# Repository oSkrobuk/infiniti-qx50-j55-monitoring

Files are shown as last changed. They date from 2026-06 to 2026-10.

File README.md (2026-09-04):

# Infiniti QX50 J55 Monitoring

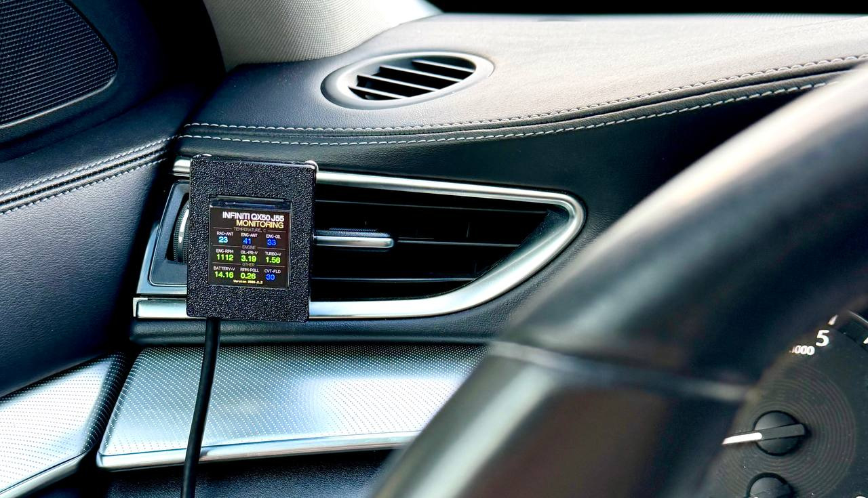
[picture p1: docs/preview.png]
Infiniti QX50 J55 Monitoring


Infiniti QX50 J55 Monitoring — компактный бортовой монитор для Infiniti QX50 J55. Он показывает
важные параметры двигателя, вариатора и бортовой сети на отдельном дисплее, а при опасных
значениях привлекает внимание цветом и звуковым сигналом.

## Что умеет устройство

- показывает температуры моторного масла, охлаждающей жидкости двигателя, радиатора и масла CVT
- отображает обороты двигателя, напряжение бортовой сети, давление масла и наддув
- выделяет нормальные, переходные и опасные значения разными цветами
- подаёт звуковой сигнал и показывает предупреждение при выходе параметров за заданные пределы
- сохраняет журнал предупреждений
- позволяет смотреть текущие показатели и менять настройки с телефона через веб-интерфейс
- поддерживает обновление прошивки по WiFi и возврат к предыдущей версии

## Что показывает дисплей

На дисплее показаны девять метрик в трёх группах. Обозначения одинаковы на дисплее и на странице
онлайн-мониторинга в веб-интерфейсе.

| Группа | Метка | Что означает | Единица |
|---|---|---|---|
| Температура | **RAD-ANT** | Температура охлаждающей жидкости в радиаторе | °C |
| Температура | **ENG-ANT** | Температура охлаждающей жидкости двигателя | °C |
| Температура | **ENG-OIL** | Температура моторного масла | °C |
| Двигатель | **ENG-RPM** | Обороты двигателя | об/мин |
| Двигатель | **OIL-PR-V** | Напряжение датчика давления масла | В |
| Двигатель | **TURBO-V** | Напряжение датчика давления наддува | В |
| Прочее | **BATTERY-V** | Напряжение бортовой сети | В |
| Прочее | **RPM-POLL** | Интервал между обновлениями оборотов | с |
| Прочее | **CVT-FLD** | Температура масла вариатора | °C |

`OIL-PR-V` и `TURBO-V` показывают напряжение, которое поступает от соответствующего датчика, а не
давление в физических единицах. `RPM-POLL` — не время ответа блока управления, а фактическая
частота обновления показаний оборотов: чем меньше значение, тем быстрее обновляются данные.

Цвет показания помогает оценить его состояние:

| Цвет | Значение |
|---|---|
| 🔵 Синий | Данных нет, агрегат не прогрет или ещё не готов к работе |
| 🟢 Зелёный | Нормальный рабочий диапазон |
| 🟡 Жёлтый | Переходная зона |
| 🔴 Красный | Значение вышло за пределы нормы |

Пороговые значения и цветовые зоны можно изменить через веб-интерфейс.

## Предупреждения и их значения

Если опасное значение сохраняется дольше настроенного времени подтверждения, устройство подаёт
звуковой сигнал, на пять секунд показывает код предупреждения поверх метрик и сохраняет событие
в журнале. Пороги в таблице указаны для заводской конфигурации и могут быть изменены
через настройки в браузере по адресу [http://192.168.4.1](http://192.168.4.1), подключившись
по WiFi (см. раздел [«WiFi и веб-интерфейс»](#wifi-и-веб-интерфейс)).

| Код | Что означает | Заводской порог |
|-----|---|---|
| **E01** | Температура моторного масла слишком высокая | Выше 98 °C |
| **E02** | Температура охлаждающей жидкости двигателя слишком высокая | Выше 96 °C |
| **E03** | Температура охлаждающей жидкости в радиаторе слишком высокая | Выше 90 °C |
| **E04** | Температура масла вариатора слишком высокая | Выше 100 °C |
| **E05** | Превышены допустимые обороты двигателя | Выше 6500 об/мин |
| **E06** | Напряжение бортовой сети слишком низкое | Ниже 11,5 В |
| **E07** | Напряжение бортовой сети слишком высокое | Выше 15,0 В |
| **E08** | Сигнал датчика давления масла ниже нормы для текущих оборотов | Ниже 1,4 В до 3000 об/мин или ниже 2,9 В от 3000 об/мин |
| **E09** | Разница температур масла и охлаждающей жидкости двигателя слишком высокая | Выше 14 °C |

Наличие кода в журнале означает, что такое состояние было зафиксировано ранее: оно не обязательно
сохраняется в текущий момент. Текущие значения следует проверить на дисплее или странице
онлайн-мониторинга. После очистки журнала предупреждение появится снова, если причина не устранена.

## Что требуется от пользователя

После установки и подключения — ничего. Не нужно запускать приложение, создавать учётную запись,
подключать устройство к интернету или выполнять какие-либо действия перед поездкой. Включите
зажигание — монитор включится вместе с автомобилем и начнёт работать автоматически.

Устройство получает данные через штатную автомобильную шину CAN. Она предназначена для обмена
данными между электронными блоками автомобиля и диагностическим оборудованием; монитор использует
стандартные диагностические запросы для чтения показателей.

## WiFi и веб-интерфейс

WiFi нужен только тогда, когда вы хотите открыть настройки или посмотреть показатели в браузере.
Интернет для соединения с устройством не требуется.

1. Подключитесь с телефона или ноутбука к сети `QX50Monitoring`
2. Введите пароль `infiniti`
3. Откройте в браузере [http://192.168.4.1](http://192.168.4.1)

В веб-интерфейсе доступны текущие показатели, отдельная страница работоспособности устройства,
журнал предупреждений, настройка порогов, режимов оповещения и яркости поддерживаемых дисплеев,
изменение имени и пароля WiFi, а также обновление прошивки. На Android при вопросе
о сети без доступа к интернету выберите «Остаться подключённым». Мобильный интернет отключать не
нужно.

Страница [http://192.168.4.1/obd](http://192.168.4.1/obd) показывает поддерживаемые
стандартные OBD-II Mode 01 PID и девять уже используемых Infiniti UDS DID. Все PID
по умолчанию выключены и выбираются галочками. Пока страница открыта, прошивка раз в секунду
запрашивает каждый выбранный PID с настраиваемой паузой между запросами (по умолчанию 5 мс);
после закрытия опрос автоматически прекращается.
Основной опрос Infiniti DID всегда имеет приоритет и продолжает работать независимо от
диагностической страницы.

## Обновления и оплата

Обновлять прошивку регулярно не обязательно. Если устройство работает так, как вам нужно, можно
вообще не устанавливать новые версии. Обновление имеет смысл только ради новых возможностей или
нужного вам исправления и выполняется через веб-интерфейс.

Использование устройства бесплатно: нет подписки, обязательных платежей, платной активации или
облачного сервиса. Устройство работает автономно и не зависит от внешнего сервера.

## Лицензия

Проект предоставлен на условиях PolyForm Noncommercial License 1.0.0. Разрешены
использование, копирование, изменение и распространение в некоммерческих целях
при соблюдении условий лицензии. Любое коммерческое использование запрещено.
Полные условия находятся в файле [LICENSE](LICENSE).

## Дополнительная документация

- [Технические нюансы и подробное описание](docs/technical-details.md)
- [Сборка, подключение и первоначальная настройка](docs/build-and-setup.md)

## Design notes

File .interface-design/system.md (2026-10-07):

# Kanvex Web Interface

## Direction

- Feel: compact automotive diagnostic console with calm, technical hierarchy
- Domain cues: CAN bus, live telemetry, ECU diagnostics, warning states, workshop instruments
- Color world: graphite dashboard, black trim, muted steel, Infiniti gold, semantic green/red/blue
- Signature: gold diagnostic labels and large monospaced live values on dark instrument-like surfaces

## Depth and spacing

- Use borders-only depth with quiet dark surface shifts; avoid decorative shadows and gradients
- Base spacing unit: 4 px
- Control gaps: 8–12 px; card padding: 14–16 px; section gaps: 24–28 px
- Buttons use an 8 px radius; cards use 10 px; dialogs use 12 px

## Hierarchy

- Live numeric values are the focal elements: 25 px, semibold, monospaced
- Metric names are secondary and muted; PID/DID identifiers use the gold accent
- Supporting notes use muted text with approximately 1.45 line height
- Preserve the established graphite-and-gold palette and existing system font stack

## Navigation pattern

- Main navigation uses equal-width grid buttons with centered labels and visible icons
- Desktop: three equal columns, centered, with a maximum total width of 700 px
- Up to 640 px: two equal columns; an unpaired final button keeps one-column width and never stretches across the row
- Mobile navigation buttons have a minimum height of 54 px and may wrap labels without horizontal scrolling
- Keep every primary destination visible without a menu or disclosure control

## Diagnostic cards

- Use the existing bordered dark card with gold PID/DID identifier, muted name, and monospaced value
- Put contextual help in a native button and native dialog
- Dim stale values without hiding enabled controls
- Convert raw OBD values only when the PID formula is verified; explain bit fields or discarded status flags in help text

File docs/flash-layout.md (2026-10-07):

# Разделы флеш-памяти

Расчет обновлен 7 октября 2026 года по бинарникам четырех окружений после полной сборки
`platformio run`.

## Размеры прошивки

| Окружение | Размер `firmware.bin` | Размер OTA-слота | Свободно | Заполнение |
|---|---:|---:|---:|---:|
| `esp32` | 1 191 920 байт | 1 835 008 байт | 643 088 байт | 64,9% |
| `esp32-mock` | 1 186 464 байта | 1 835 008 байт | 648 544 байта | 64,7% |
| `esp32s3-wt32` | 1 227 872 байта | 6 553 600 байт | 5 325 728 байт | 18,7% |
| `esp32s3-wt32-mock` | 1 219 664 байта | 6 553 600 байт | 5 333 936 байт | 18,6% |

После интеграции BLE фактический размер нужно проверить повторно. CI ограничивает DEVKIT1 размером
старого OTA-слота `0x1C0000` (1 835 008 байт), независимо от дальнейших изменений CSV.

## ESP32 DEVKIT1, 4 МБ

Используется [`partitions_4mb.csv`](../partitions_4mb.csv):

| Раздел | Смещение | Размер |
|---|---:|---:|
| `nvs` | `0x9000` | 20 КБ |
| `otadata` | `0xE000` | 8 КБ |
| `ota_0` | `0x10000` | 1,75 МБ |
| `ota_1` | `0x1D0000` | 1,75 МБ |
| `spiffs` | `0x390000` | 448 КБ |

Два одинаковых OTA-слота сохраняют обновление с откатом. NVS в 20 КБ остается на прежнем
месте, а LittleFS на 448 КБ хранит JSON-файлы конфигурации и журналов. Веб-интерфейс
скомпилирован в прошивку.

## WT32-SC01 Plus, 16 МБ

Используется [`partitions_16mb.csv`](../partitions_16mb.csv). Раскладка совпадает с базовой
`default_16MB.csv` Arduino ESP32, но закреплена в репозитории явно:

| Раздел | Смещение | Размер |
|---|---:|---:|
| `nvs` | `0x9000` | 20 КБ |
| `otadata` | `0xE000` | 8 КБ |
| `ota_0` | `0x10000` | 6,25 МБ |
| `ota_1` | `0x650000` | 6,25 МБ |
| `spiffs` | `0xC90000` | 3,375 МБ |
| `coredump` | `0xFF0000` | 64 КБ |

Старая общая 4-мегабайтная таблица оставляла на WT32 неразмеченными 12 582 912 байт, то есть
ровно 12 МБ. Новая таблица использует все 16 МБ и оставляет большой запас для BLE и дальнейшего
роста прошивки.

## Переход существующих устройств

OTA обновляет только неактивный раздел приложения и не записывает таблицу разделов. Один и тот же
`firmware.bin` использует таблицу разделов, уже установленную на устройстве, поэтому обычное
Wi-Fi-обновление не требует миграции разметки. Устройства с временно выпускавшейся увеличенной
разметкой (слоты по 1,875 МБ и LittleFS 192 КБ) продолжают работать с ней после OTA.

USB-комплект содержит текущую классическую таблицу. Запись `partitions.bin` на устройство с
увеличенной разметкой меняет адрес и размер LittleFS и может сделать настройки и журналы
недоступными. Обычное обновление выполняйте по Wi-Fi только файлом `firmware.bin`. Менять таблицу
через USB можно лишь отдельной процедурой после резервного копирования данных и проверки текущей
разметки; Kanvex Service Tool пока не автоматизирует безопасную миграцию.

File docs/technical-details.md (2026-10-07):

# Технические нюансы Infiniti QX50 J55 Monitoring

Infiniti QX50 J55 Monitoring

Бортовой монитор на ESP32 с TFT-дисплеем и веб-интерфейсом настройки.
Считывает параметры автомобиля через диагностический протокол UDS (ISO 14229) по шине CAN (OBD-II).
При выходе параметров за пределы нормы — воспроизводит звуковой сигнал через бузер и показывает оверлей на дисплее.

В версии прошивки XXXX.Y.Z каждое число означает следующее:
1. XXXX — год выпуска релиза прошивки.
2. Y — мажорная версия (Major). Указывает на крупные изменения, новые функции или глобальное обновление архитектуры.
3. Z — минорная версия (Minor). Указывает на мелкие доработки, исправления ошибок или добавление небольших возможностей в рамках текущего мажора.

Версия задается в одном месте — `FW_VERSION` в [include/Version.h](../include/Version.h). Оттуда она
попадает на дисплей, в `GET /version` и `GET /metrics`, и с ней же CI сверяет имя тега при релизе.

---

## Поддерживаемые платформы

| Платформа | Дисплей | Окружение сборки |
|---|---|---|
| **ESP32 DEVKIT1** | ST7789 240×240 SPI | `esp32`, `esp32-mock` |
| **WT32-SC01 Plus ESP32-S3** | ST7796 320×480 8-бит параллельный | `esp32s3-wt32`, `esp32s3-wt32-mock` |

---

## Необходимое оборудование

### Вариант A: ESP32 DEVKIT1

| Компонент | Описание |
|---|---|
| **ESP32 DEVKIT1** | Основной микроконтроллер. Любая плата на базе ESP32 с 30 или 38 пинами (DEVKIT V1 / DOIT). |
| **IPS TFT ST7789** | Дисплей 240×240 пикселей, интерфейс SPI, питание 3.3 В. |
| **WVCMCU-230** | CAN-трансивер на базе SN65HVD230, питание 3.3 В, подключается к OBD-II разъёму автомобиля. |
| **Пассивный бузер** | Пьезоизлучатель для звукового оповещения об алертах. Подключается к GPIO 26 через резистор 1кОм и 2N5551. |
| **DC-DC** | Преобразователь напряжения 12–24 В в 5 В. |
| **Провода** | Соединительные провода (желательно разных цветов для удобства монтажа). |
| **Паяльник + припой** | Для надёжного соединения проводов с платами. |

### Вариант B: WT32-SC01 Plus ESP32-S3

| Компонент | Описание |
|---|---|
| **WT32-SC01 Plus** | Плата с встроенным дисплеем ST7796 320×480 и ESP32-S3-WROVER-N16R2 (16 МБ Flash, 2 МБ PSRAM). |
| **WVCMCU-230** | CAN-трансивер на базе SN65HVD230, питание 3.3 В, подключается к OBD-II разъёму автомобиля. |
| **Пассивный бузер** | Пьезоизлучатель для звукового оповещения об алертах. Подключается к GPIO 12 через резистор 1кОм и 2N5551. |
| **DC-DC** | Преобразователь напряжения 12–24 В в 5 В. |
| **Провода** | Соединительные провода (желательно разных цветов для удобства монтажа). |
| **Паяльник + припой** | Для надёжного соединения проводов с платами. |

> Дисплей встроен в плату WT32-SC01 Plus и не требует отдельного подключения.
> Яркость встроенной подсветки регулируется через аппаратный BL_PWM на GPIO 45.

---

## 1. Подключение оборудования

### TFT-дисплей (ST7789, 240×240) — только для ESP32 DEVKIT1

| Дисплей | ESP32 GPIO | Описание |
|---|---|---|
| SDA / MOSI | GPIO **23** | Данные SPI |
| SCL / SCLK | GPIO **18** | Тактирование SPI |
| RES / RST  | GPIO **4**  | Сброс дисплея |
| DC / RS | GPIO **15** | Данные / команда |
| BLK | GPIO **27** через 500 Ом | Управление яркостью, если вывод есть |
| CS | — | Не подключать (CS=-1, дисплей всегда выбран) |
| VCC | **3.3 В** | Питание |
| GND | **GND** | Земля |

> Дисплей работает на 3.3 В. Не подключайте к 5 В — это выведет его из строя.
>
> Вывод BLK необязателен. Одна и та же прошивка работает с дисплеями без BLK и с дисплеями, у которых
> BLK подключен к GPIO 27. Во втором случае яркость регулируется через веб-интерфейс от 10 до 100%.
> Если BLK конкретного модуля напрямую питает светодиоды, а не является управляющим входом,
> используйте транзистор или MOSFET согласно документации модуля.

---

### Питание WT32-SC01 Plus

Преобразователь DC-DC понижает бортовое напряжение 12–14 В до 5 В. Выход `+5 В` подключается к
контакту 1 разъема `EXT_IO_1`, а выход `GND` — к контакту 2. Контакты считаются слева направо,
если смотреть на плату так же, как на схеме подключения.

Питание 3,3 В для WVCMCU-230 и цепи пассивного бузера берется с контакта 2 разъема `EXT_IO_2`,
второго слева. Земля CAN-трансивера и бузера подключается непосредственно к `GND` выхода DC-DC;
таким образом, все компоненты имеют общую землю.

---

### CAN-модуль WVCMCU-230 (SN65HVD230) — для обеих платформ

| Модуль | ESP32 DEVKIT1 | WT32-SC01 Plus | Описание |
|---|---|---|---|
| CTX | GPIO **32** | GPIO **10**, `EXT_IO_1` контакт 3 слева | CAN TX (МК → трансивер) |
| CRX | GPIO **34** | GPIO **11**, `EXT_IO_1` контакт 4 слева | CAN RX (трансивер → МК) |
| VCC | **3,3 В** | **3,3 В**, `EXT_IO_2` контакт 2 слева | Питание |
| GND | **GND** | `GND` выхода DC-DC | Общая земля |
| CANH | OBD-II пин **6** | OBD-II пин **6** | Шина CAN High |
| CANL | OBD-II пин **14** | OBD-II пин **14** | Шина CAN Low |

> На WT32-SC01 Plus GPIO 10 и GPIO 11 выведены на разъем `EXT_IO_1` и не конфликтуют со встроенными
> дисплеем и сенсорной панелью.

> ESP32 активно опрашивает блоки управления двигателем (ECM) и трансмиссией (TCM) по протоколу UDS, отправляя запросы `ReadDataByIdentifier` (сервис 0x22). Это безопасно: запросы стандартны, используются штатным дилерским оборудованием.

> Скорость шины: **500 кбит/с** (стандарт для большинства автомобилей, в т.ч. Infiniti QX50 J55).

---

### Пассивный бузер — для обеих платформ

| Бузер | ESP32 DEVKIT1 | WT32-SC01 Plus | Описание |
|---|---|---|---|
| Питание | **3,3 В** | **3,3 В**, `EXT_IO_2` контакт 2 слева | Питание бузера |
| Управление | GPIO **26** | GPIO **12**, `EXT_IO_1` контакт 5 слева | Через резистор 1 кОм и 2N5551 |
| GND | **GND** | `GND` выхода DC-DC | Общая земля |

При включении устройства бузер воспроизводит короткую мелодию приветствия (в стиле BIOS POST). При срабатывании алерта — сигнал оповещения.

> На WT32-SC01 Plus есть встроенный I2S-усилитель 2,5 Вт и выход `SPK+/SPK-`, но самого динамика
> на плате нет. Текущая прошивка этот выход не использует и воспроизводит сигналы внешним пассивным
> бузером на GPIO 12.

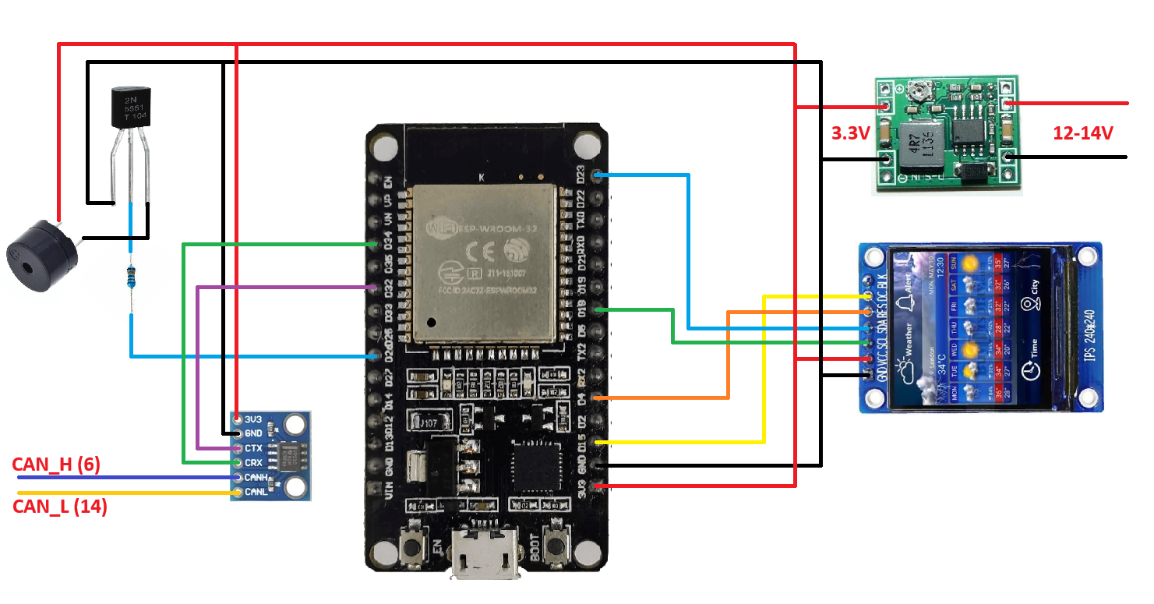
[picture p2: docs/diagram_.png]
Схема подключения ESP32 DEVKIT1


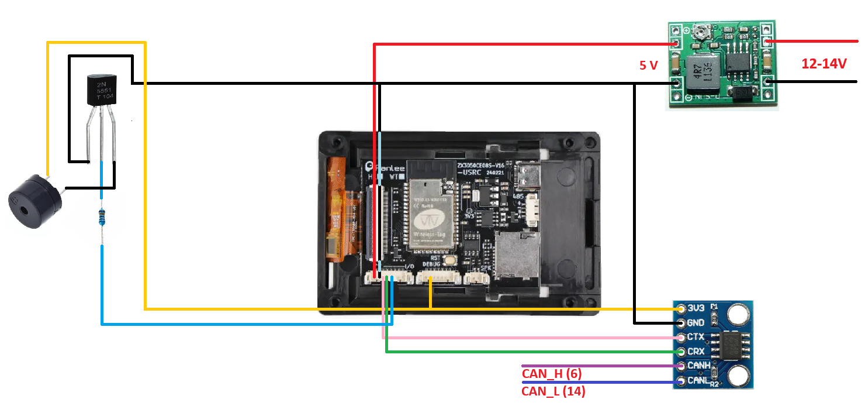
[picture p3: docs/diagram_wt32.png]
Схема подключения WT32-SC01 Plus


---

### Корпус

Корпус для дисплея 1,3″ печатаем на 3D-принтере пластиком PETG или ABS. Есть два варианта корпуса:

1. [Первая версия](../stl/full_v1_1.3in_display.stl)
2. Измененная Александром: [корпус МК](../stl/mc_housing_v2),
   [корпус дисплея](../stl/display_housing_v2_1.3in). Отличается переносом и
   углублением отверстий под провода, дополнительным зажимом на крышке МК и простым
   креплением дисплея в дефлектор

---

## 2. USB-устройство в WSL

ESP32 DEVKIT1 подключается через мост CP2102, CH340 или CH9102. WT32-SC01 Plus
использует встроенный USB Serial/JTAG. Передайте USB-устройство в WSL и проверьте
доступный Linux-порт:

```bash
ls -l /dev/ttyUSB* /dev/ttyACM* 2>/dev/null
```

Обычно DEVKIT1 появляется как `/dev/ttyUSB0`, а WT32 — как `/dev/ttyACM0`. Если
у текущего пользователя нет доступа к порту, добавьте его в группу `dialout`, затем
перезапустите сеанс WSL:

```bash
sudo usermod -aG dialout "$USER"
```

---

## 3. Первичная прошивка из WSL через esptool

Команды этого раздела выполняет только владелец устройства. Для ESP32 DEVKIT1 нужны
`bootloader.bin`, `partitions.bin` и `firmware.bin`:

```bash
python3 -m esptool --chip esp32 --port /dev/ttyUSB0 --baud 921600 erase_flash
python3 -m esptool --chip esp32 --port /dev/ttyUSB0 --baud 921600 \
  write_flash --flash_mode dio --flash_freq 40m \
  0x1000 bootloader.bin 0x8000 partitions.bin 0x10000 firmware.bin
```

Для WT32-SC01 Plus нужны `bootloader_s3.bin`, `partitions_s3.bin` и
`firmware_s3.bin`. Загрузчик от ESP32 DEVKIT1 использовать нельзя:

```bash
python3 -m esptool --chip esp32s3 --port /dev/ttyACM0 --baud 460800 erase_flash
python3 -m esptool --chip esp32s3 --port /dev/ttyACM0 --baud 460800 \
  write_flash --flash_mode qio --flash_freq 80m --flash_size 16MB \
  0x0000 bootloader_s3.bin 0x8000 partitions_s3.bin 0x10000 firmware_s3.bin
```

Для входа WT32 в загрузчик подключите плату по USB-C, зажмите `BOOT`, нажмите и
отпустите `RESET`, затем отпустите `BOOT`. После прошивки нажмите `RESET`.

---

## 4. Мониторинг UART из WSL

Подключите терминал PlatformIO к тому же Linux-порту со скоростью 115200 бод:

```bash
platformio device monitor --port /dev/ttyUSB0 --baud 115200
```

Для WT32 обычно нужно заменить порт на `/dev/ttyACM0`. После нажатия `EN` или
`RESET` в терминале появится журнал загрузки, состояние CAN-шины, ответы UDS,
значения датчиков и срабатывания алертов.

> Если в окне нет вывода — проверьте правильность порта COM и скорость 115200. Порт должен совпадать с тем, что отображается в Диспетчере устройств (**Silicon Labs CP210x**).

> **Предупреждения при старте — это нормально.** При каждом включении ESP32 ROM-загрузчик выводит несколько служебных строк на скорости 74880 бод (не 115200), поэтому терминал может показать их как мусор: `RX FRAMING ERROR`, `invalid UTF-8 byte sequence`, `No core dump partition found`. Эти сообщения не относятся к нашему коду и не влияют на работу устройства — просто игнорируйте их.

---

## 5. Подключение к WiFi и веб-интерфейс

ESP32 создаёт собственную точку доступа (Access Point) — интернет не нужен.

| Параметр | Значение по умолчанию |
|---|---|
| Сеть | `QX50Monitoring` |
| Пароль | `infiniti` |
| Адрес | http://192.168.4.1 |

> Имя сети и пароль можно изменить через веб-интерфейс (раздел **«1. Настройка WiFi»**).
> После сохранения устройство перезагрузится с новыми настройками.

**Шаги:**

1. На телефоне или ноутбуке откройте список WiFi-сетей.
2. Подключитесь к сети **QX50Monitoring**, пароль `infiniti`.
3. Откройте браузер и перейдите по адресу **http://192.168.4.1**.
4. Откроется страница редактора конфигурации.
5. Можно забыть WiFi-сеть, чтобы телефон не подключался автоматически.

> **Мобильный интернет на телефоне продолжает работать.** Устройство намеренно не отдает
> по DHCP адрес шлюза, поэтому телефон не делает нашу сеть основной: запросы на `192.168.4.1`
> идут по WiFi, все остальные — по мобильной сети. Android при подключении спросит «Сеть не имеет
> доступа к интернету. Остаться подключенным?» — ответьте **«Да»**.
>
> Передачу данных **отключать не нужно** — без нее не работает проверка обновлений (глава 6).
> Отключить ее имеет смысл только если конкретный телефон все равно упорно теряет интернет:
> веб-интерфейс и OTA от этого работать не перестанут.

### HTTP API

| Метод | Путь | Описание |
|---|---|---|
| `GET`  | `/` | Главная страница (HTML) — редактор конфигурации |
| `GET`  | `/live` | Страница онлайн мониторинга (HTML) — метрики в реальном времени |
| `GET`  | `/health` | Страница работоспособности устройства (HTML) |
| `GET`  | `/metrics` | Текущие значения метрик и их состояния (JSON, включая `version`) |
| `GET`  | `/reset-history`  | История причин последних загрузок устройства (JSON) |
| `GET`  | `/version` | Версия прошивки, метка сборки, слот OTA, окружение, аптайм (JSON) |
| `GET`  | `/config` | Текущий конфиг порогов (JSON) |
| `POST` | `/config` | Сохранить конфиг порогов (JSON body) |
| `POST` | `/reset` | Сбросить конфиг порогов к заводским значениям |
| `GET`  | `/wifi` | Текущие WiFi-настройки (JSON: ssid, password) |
| `POST` | `/wifi` | Сохранить WiFi-настройки (JSON body) |
| `POST` | `/restart` | Перезагрузить устройство |
| `GET`  | `/alerts` | Журнал сработавших алертов (JSON) |
| `POST` | `/alerts-clear` | Очистить журнал алертов |
| `GET`  | `/checks` | Конфиг проверок алертов (JSON) |
| `POST` | `/checks` | Сохранить конфиг проверок (JSON body) |
| `GET`  | `/update` | Страница OTA-обновления прошивки (редирект на `/`) |
| `POST` | `/update` | Загрузить `.bin` файл прошивки (multipart) |
| `GET`  | `/slots` | Что записано в обоих слотах OTA (JSON) |
| `POST` | `/boot-slot` | Сделать слот загрузочным (`?slot=ota_0` или `?slot=ota_1`) |

Ответ `GET /version`:

```json
{
  "version": "2026.3.1",
  "build": "Jul 27 2026 14:02:11",
  "slot": "ota_0",
  "env": "esp32",
  "uptime_s": 12345
}
```

`slot` — раздел, из которого загрузилась работающая прошивка (`ota_0` или `ota_1`),
`env` — окружение сборки (`esp32`, `esp32-mock`, `esp32s3-wt32`, `esp32s3-wt32-mock`).

Ответ `GET /slots`:

```json
{
  "slots": [
    {
      "label": "ota_0", "valid": true, "running": true, "boot": true, "compatible": true,
      "version": "2026.3.3", "env": "esp32", "build": "Aug  6 2026 01:15:19",
      "size": 1835008, "used": 1080325, "address": 65536
    },
    {
      "label": "ota_1", "valid": true, "running": false, "boot": false, "compatible": true,
      "version": "2026.3.2", "env": "esp32", "build": "Aug  3 2026 04:49:07",
      "size": 1835008, "used": 1076032, "address": 1900544
    }
  ]
}
```

`valid` — в слоте лежит образ приложения, `running` — из него работает прошивка сейчас,
`boot` — с него устройство загрузится после перезагрузки, `compatible` — разрешено ли ручное
переключение, `used` — длина образа в байтах, `address` — адрес раздела во flash.
Пустые `version`, `env` и `build` означают, что в образе нет маркера версии (прошивка старее
этой возможности) — см. главу 6.

### Онлайн мониторинг (веб)

Страница **http://192.168.4.1/live** (ссылка **«📊 Онлайн мониторинг →»** на главной)
показывает все метрики в реальном времени прямо в браузере — удобно, когда дисплей не виден.

- **Сетка метрик** — 9 карточек по 3 в ряд, в том же порядке, что и на дисплее:
  RAD-ANT · ENG-ANT · ENG-OIL / ENG-RPM · OIL-PR-V · TURBO-V / BATTERY-V · RPM-POLL · CVT-FLD.
  Значения обновляются каждые **0.5 сек** (опрос `/metrics`), цвет левой полосы и числа
  отражает состояние (синий / зелёный / жёлтый / красный / серый «нет данных»).
- **Индикатор связи** — строка «В сети · v2026.3.1 · обновлено ЧЧ:ММ:СС · аптайм …» либо
  «Нет связи с устройством». Версия прошивки приходит в том же ответе `/metrics`.
- **Баннер ошибок** — красная плашка «⚠ Зафиксированы ошибки…» появляется, если в журнале
  есть срабатывания, и исчезает после его очистки.
- **История срабатываний** — та же таблица журнала алертов, что и на главной, с кнопкой
  **«🗑 Очистить историю»**. Обновляется каждые **5 сек** и сразу после очистки.

---

## 6. OTA — обновление прошивки по воздуху

После первой прошивки через USB все последующие обновления можно загружать **без кабеля** прямо через браузер.

### Что нужно

- Файл `firmware.bin` новой версии (из релиза или собранный PlatformIO: `.pio/build/esp32/firmware.bin`).
- Подключение к точке доступа **QX50Monitoring**.

### Порядок обновления

1. Подключитесь к WiFi-сети **QX50Monitoring** (пароль `infiniti`).
2. Откройте **http://192.168.4.1** в браузере.
3. Прокрутите страницу вниз до раздела **«↑ OTA — Обновление прошивки»**.
4. Нажмите **«Выбрать .bin»** и укажите файл `firmware.bin`.
5. Нажмите **«↑ Загрузить»** и подтвердите в диалоге.
6. Дождитесь заполнения прогресс-бара и сообщения **«✓ Прошивка записана. Перезагрузка...»**.
7. ESP32 автоматически перезагрузится с новой прошивкой (~2–3 секунды).

> **Страница перестанет отвечать** на время перезагрузки — это нормально. Через 5–10 секунд обновите страницу браузера.

> **Первичная прошивка через USB обязательна.** OTA-обновления возможны только после того, как устройство хотя бы один раз прошито через USB с помощью `esptool` или PlatformIO.

### Проверка обновлений

В том же разделе **«↑ 6. Обновление прошивки»**, над формой загрузки `.bin`, лежит карточка
**«↻ Проверка обновлений»**: текущая версия прошивки, метка сборки со слотом OTA и кнопка
**«↻ Проверить обновления»**.

Устройство в интернет не выходит, поэтому релизы спрашивает **браузер телефона**: запрос
на `192.168.4.1` идет по WiFi, запрос к `api.github.com` — по мобильной сети.

**Автопроверка при открытии страницы.** Главная страница проверяет релизы сама, в фоне —
загрузку и работу интерфейса это не задерживает, а при отсутствии интернета просто ничего
не происходит. Если на GitHub версия новее, поверх страницы появляется окно **«↑ Доступна
новая прошивка»** с кнопками **«Перейти к обновлению»** (открывает и прокручивает к разделу 5)
и **«Позже»**; окно закрывается также кликом по затемнению или клавишей Esc.

Проверка идет не чаще **одного раза в 5 минут**: время последней попытки лежит
в `localStorage` браузера, поэтому перезагрузка страницы, закрытие вкладки и перезапуск
браузера отсчет не сбрасывают — иначе несколько открытий страницы подряд быстро упирались бы
в лимит GitHub. Кнопка **«↻ Проверить обновления»** этот интервал игнорирует и работает всегда.

**Что нужно от телефона:**

- включенная передача данных (мобильный интернет);
- разрешение остаться в сети без интернета — на вопрос Android «Сеть не имеет доступа
  к интернету. Остаться подключенным?» ответьте **«Да»**.

**Что показывает кнопка:**

| Ситуация | Сообщение |
|---|---|
| Есть версия новее | «Доступна версия X (у вас Y)» + описание релиза и ссылки на релиз и `firmware.bin` |
| Установлена актуальная | «✓ Установлена последняя версия X» |
| Релизов нет | «Релизы еще не опубликованы» |
| Слишком частые проверки | «Превышен лимит запросов к GitHub, попробуйте позже» — без авторизации GitHub отдает 60 запросов в час на один адрес |
| Нет интернета у телефона | «Нет доступа к интернету» + напоминание включить мобильные данные |

Запрос обрывается через **5 секунд**: в сети без интернета DNS не отвечает, и ждать дольше
нечего. Ссылка **«Все релизы»** под карточкой ведет на страницу релизов напрямую и работает,
даже если проверка не прошла.

Если релиз новее, в карточке появляется кнопка **«↓ Скачать и установить»**: браузер сам скачивает
OTA-образ для подключенной платы и сразу отдает его в прошивку, прогресс идет в полосе формы ниже.

Файл берется не из ассетов релиза, а из служебной ветки `firmware`. WEB UI выбирает его
по окружению сборки устройства:

```
https://raw.githubusercontent.com/oSkrobuk/infiniti-qx50-j55-monitoring/firmware/<версия>/firmware.bin
https://raw.githubusercontent.com/oSkrobuk/infiniti-qx50-j55-monitoring/firmware/<версия>/firmware_s3.bin
```

Ассеты релизов GitHub отдает с хоста `release-assets.githubusercontent.com` **без заголовка
`Access-Control-Allow-Origin`**, и браузер не пускает такой ответ в скрипт — запрос падает
еще до чтения файла (Safari сообщает об этом первым, но так ведут себя все браузеры).
У `raw.githubusercontent.com` заголовок есть, поэтому CI на каждом теге кладет прошивку
еще и в ветку `firmware`, в папку с номером версии. Версия в пути означает, что на
устройство не может приехать `.bin` от другого релиза.

Если скачать не удалось (сборки этой версии в ветке еще нет, оборвалась сеть), в карточке
появляется подсказка с причиной — скачайте `.bin` вручную по ссылке и залейте формой
**«↑ OTA — Загрузка .bin»**. Ручной способ работает всегда: обычное скачивание по ссылке
идет средствами браузера, и CORS ему не нужен.

Для ESP32 DEVKIT1 скачивается `firmware.bin`, для WT32-SC01 Plus — `firmware_s3.bin`.

### Проверка совместимости OTA-образа

Автоматическая и ручная OTA-загрузка проходят одинаковую проверку на самом устройстве. Во время
приема файла прошивка ищет встроенный маркер `QX50-FW-TAG`, читает из него окружение сборки и до
активации нового слота сравнивает его с работающей платой.

Совместимыми считаются real- и mock-сборки одной аппаратной платформы:

- `esp32` и `esp32-mock` — ESP32 DEVKIT1
- `esp32s3-wt32` и `esp32s3-wt32-mock` — WT32-SC01 Plus

Автоматическое обновление mock-сборки загружает опубликованный real-образ той же платы. После
обновления устройство продолжит работу уже без симуляции данных.

Образ WT32 нельзя установить на ESP32 DEVKIT1 и наоборот. Файл без маркера, в том числе старая
или сторонняя прошивка, также отклоняется. Проверка выполняется до `Update.end(true)`, поэтому
отклоненный образ не становится загрузочным, а устройство продолжает работать с текущего слота.

Ограничение относится только к OTA через веб-интерфейс. При необходимости старый образ без маркера
по-прежнему можно записать вручную через USB-инструменты.

### Слоты прошивки и откат

Под карточкой проверки обновлений лежит карточка **«⇆ Слоты прошивки»**: для каждого из двух
слотов (`ota_0` и `ota_1`) видно, что в нем записано — версия, окружение сборки, дата сборки
и размер образа, — а также метки **«работает сейчас»** и **«загрузится после перезагрузки»**.

Кнопка **«⇆ Загрузиться отсюда»** у совместимого неактивного слота переключает загрузку на лежащую там
прошивку: устройство меняет запись в `otadata` и перезагружается. Так возвращаются к предыдущей
версии, если новая чем-то не устроила — заново качать `.bin` не нужно, старый образ никуда
не делся. Настройки, журнал алертов и файловая система лежат в отдельном разделе `spiffs`,
поэтому переключение слота их не меняет. Однако старая прошивка получает текущую конфигурацию,
которая может оказаться для нее несовместимой; автоматического отката после неудачной загрузки нет.

> Версию соседнего слота устройство читает прямо из его образа: при сборке в прошивку
> вшивается маркер `QX50-FW-TAG:версия|окружение|дата сборки|`, и он ищется линейным чтением
> раздела (результат кешируется по хешу образа, так что повторные открытия карточки бесплатны).
> У прошивок, собранных до появления этой карточки, маркера нет — для них показывается
> «Версия неизвестна», а ручное переключение запрещено. Сервер повторяет проверку образа,
> поэтому обойти ограничение прямым запросом к HTTP API нельзя.

### Как устроено OTA (техническая справка)

Для плат используются разные таблицы разделов. ESP32 DEVKIT1 с 4 МБ флеша получает два
OTA-слота по 1,75 МБ и LittleFS на 448 КБ. WT32-SC01 Plus с 16 МБ получает два слота по
6,25 МБ, LittleFS на 3,375 МБ и раздел coredump на 64 КБ. Полный расчет, размеры текущих
бинарников и порядок перехода приведены в [описании разделов флеша](flash-layout.md).

При OTA-обновлении:
1. Новая прошивка записывается в **неактивный** слот.
2. `otadata` обновляется, указывая на новый слот.
3. ESP32 перезагружается и загружается из нового слота.

Старая прошивка остаётся в предыдущем слоте до следующего OTA-обновления, и на нее можно
вернуться карточкой **«⇆ Слоты прошивки»**.

### Файлы LittleFS

В разделе `spiffs` (LittleFS, 448 КБ на ESP32 и 3,375 МБ на WT32) хранятся четыре файла:

| Файл | Описание |
|---|---|
| `/config.json` | Пороги метрик, параметры системы, яркость и настройки WiFi |
| `/checks.json` | Конфиг проверок алертов (тайминги + режим повтора + пороги) |
| `/alerts.json` | Журнал сработавших алертов (сохраняется между перезагрузками) |
| `/resets.json` | Причины последних десяти загрузок устройства |

---

## 7. Метрики на дисплее

Дисплей 240×240 разделён на три секции. Цвет каждого значения меняется плавно согласно настроенным порогам.

При срабатывании алерта дисплей переходит в **режим оверлея** — метрики скрываются и на весь экран отображается код и описание алерта (например, `E01 — Engine oil temperature exceeded maximum threshold`). Оверлей исчезает автоматически через **5 секунд**.

### TEMPERATURE — температурные датчики

| Метка | Описание | Единица |
|---|---|---|
| **RAD-ANT** | Температура антифриза в радиаторе | °C |
| **ENG-ANT** | Температура антифриза ДВС | °C |
| **ENG-OIL** | Температура моторного масла ДВС | °C |

Цвет меняется по схеме **синий → зелёный → красный** (холодно → норма → перегрев).

### ENGINE — параметры двигателя

| Метка | Описание | Единица |
|---|---|---|
| **ENG-RPM** | Обороты двигателя | об/мин |
| **OIL-PR-V** | Напряжение датчика давления масла ДВС | В |
| **TURBO-V** | Напряжение датчика давления наддува (турбина) | В |

### OTHER — прочие параметры

| Метка | Описание | Единица |
|---|---|---|
| **BATTERY-V** | Напряжение бортовой сети | В |
| **RPM-POLL** | Период обновления оборотов — интервал между двумя UDS-запросами RPM | с |
| **CVT-FLD** | Температура масла вариатора (CVT) | °C |

> **RPM-POLL — это не время ответа ECU.** Значение показывает, как часто устройство успевает
> обновлять обороты: отдельная задача по кругу опрашивает 8 параметров с паузой `poll_interval_ms`,
> поэтому RPM-POLL ≈ `poll_interval_ms × 8` (при 30 мс — около 0.24 с).

### Цветовая индикация

| Цвет | Значение |
|---|---|
| 🔵 Синий | Нет данных или агрегат не прогрет или не готов к работе |
| 🟢 Зелёный | Рабочий / нормальный диапазон |
| 🟡 Жёлтый | Переходная зона (плавный градиент) |
| 🔴 Красный | Выход за пределы нормы / перегрев |

---

## 8. Настройка порогов

Все пороги хранятся в файловой системе LittleFS (`/config.json`) и доступны для редактирования через веб-интерфейс.
`POST /config` принимает только известные секции и поля, проверяет типы, безопасные диапазоны и порядок порогов.
Некорректный запрос отклоняется целиком и не изменяет сохраненную конфигурацию.

Каждая карточка содержит кнопку **«↺ Сброс»** — сбрасывает поля только этой карточки к заводским значениям без сохранения. Кнопка **«↺ По умолчанию»** в разделе «Конфигурация метрик» сбрасывает весь конфиг и немедленно сохраняет его.

> При обновлении прошивки конфиг мигрирует по отдельным полям: известные пользовательские значения
> сохраняются, новые параметры получают актуальные значения по умолчанию, удаленные параметры
> отбрасываются. CRC32 блока defaults используется только для обнаружения необходимости миграции.

### 🌡️ Температурные датчики

Три порога: минимум (не прогрет), цель (рабочая температура), максимум (перегрев).

| Секция | Датчик | Мин, °C | Цель, °C | Макс, °C |
|---|---|---|---|---|
| `oil` | ENG-OIL — моторное масло ДВС | 50 | 90 | 98 |
| `coolant` | ENG-ANT — антифриз ДВС | 50 | 90 | 93 |
| `radiator` | RAD-ANT — антифриз радиатора | 0 | 50 | 90 |
| `transmission` | CVT-FLD — масло вариатора | 50 | 80 | 98 |

### ⚙️ Обороты двигателя (ENG-RPM)

Секция `rpm` — три порога цветовых зон:

| Параметр | Знач. по умолч. | Описание |
|---|---|---|
| `green_start` | 1000 об/мин | Начало зелёной зоны |
| `green_end` | 3500 об/мин | Конец зелёной зоны |
| `red_start` | 4500 об/мин | Начало красной зоны |

Ниже `green_start` — синий, выше `red_start` — красный, между зонами — плавный переход через жёлтый.

### 🛢️ Датчик давления масла ДВС (OIL-PR-V)

Секция `oil_pressure` — минимально допустимое **напряжение датчика** зависит от оборотов:

| Параметр | Знач. по умолч. | Описание |
|---|---|---|
| `rpm_threshold` | 3000 об/мин | Граница низких / высоких оборотов |
| `min_low` | 1.45 В | Минимум при RPM < threshold (красный ниже) |
| `min_high` | 3.1 В  | Минимум при RPM ≥ threshold (красный ниже) |

### 💨 Наддув (TURBO-V)

Секция `boost` — цветовые пороги напряжения датчика MAP:

| Параметр | Знач. по умолч. | Описание |
|---|---|---|
| `blue_max`  | 1.30 В | ≤ этого — синий (нет давления) |
| `green_min` | 1.58 В | ≥ этого — зелёный (наддув есть) |

Между порогами — плавный переход синий → жёлтый → зелёный.

### 🔋 Бортовая сеть (BATTERY-V)

Секция `battery` — пороги напряжения в Вольтах:

| Параметр | Знач. по умолч. | Описание |
|---|---|---|
| `red_low` | 11.5 В | Ниже — красный (разряд) |
| `green_min` | 12.0 В | Начало зелёной зоны |
| `green_max` | 14.6 В | Конец зелёной зоны |
| `red_high`  | 14.9 В | Выше — красный (перезаряд) |

### ⏱️ Период обновления RPM (RPM-POLL)

Секция `poll_time` — интервал между двумя последовательными UDS-запросами оборотов (секунды):

| Параметр | Знач. по умолч. | Описание |
|---|---|---|
| `green_max` | 0.20 с | ≤ этого — зелёный (обороты обновляются часто) |
| `red_min` | 0.50 с | ≥ этого — красный (обороты обновляются слишком редко) |

### 🔧 Системные параметры UDS-опроса

Секция `system` — управляет планировщиком запросов:

| Параметр | Знач. по умолч. | Описание |
|---|---|---|
| `poll_interval_ms` | 30 мс  | Пауза между последовательными UDS-запросами |
| `obd_request_spacing_ms` | 5 мс | Пауза между выбранными OBD PID внутри секундного пакета |
| `stale_ms` | 1000 мс | Через сколько мс без ответа значение обнуляется |

### 📶 WiFi точка доступа

Секция `wifi` — настройки AP (изменяются в разделе «1. Настройка WiFi»):

| Параметр | Знач. по умолч. | Описание |
|---|---|---|
| `ssid` | `QX50Monitoring` | Имя WiFi-сети |
| `password` | `infiniti` | Пароль WiFi-сети |

---

## 9. Система алертов

Устройство непрерывно отслеживает параметры и при выходе за пределы нормы:

1. Воспроизводит **звуковой сигнал** через внешний пассивный бузер.
2. Показывает **оверлей на дисплее** с кодом и описанием (5 секунд).
3. Записывает событие в **журнал алертов** (`/alerts.json`), который сохраняется между перезагрузками.

### Тайминги алертов

Два параметра, общих для всех девяти проверок. Задаются в секундах в разделе
**«⚠ 4. Конфигурация проверок»**, хранятся в `/checks.json` в миллисекундах:

| Параметр | Знач. по умолч. | Диапазон | Описание |
|---|---|---|---|
| `confirm_ms` | 1000 мс (1 с) | 0…60 с | Сколько условие должно держаться, прежде чем поднимется алерт |
| `retrigger_ms` | 15000 мс (15 с) | 1…3600 с | Как часто напоминать о сохраняющейся неисправности (режим повтора) |

> **Показание, выскочившее за диапазон на доли секунды, алертом не считается**: ни сигнала,
> ни записи в журнале не будет. Как только значение возвращается в норму, отсчёт начинается
> заново — то же самое происходит, если по метрике перестают приходить кадры. Подтверждение
> в `0 с` отключает эту защиту: алерт срабатывает на первом же замере за порогом.

Каждая проверка имеет два режима, которые переключаются toggle-переключателем в Web UI:

| Режим | Поведение |
|---|---|
| **При постоянной ошибке повтор раз в N сек** (toggle вкл) | Пока условие нарушено — сигнал и оверлей повторяются каждые `retrigger_ms` |
| **Однократно, пока код в журнале** (toggle выкл) | Сигнал срабатывает один раз и больше не повторяется, пока код остаётся в журнале алертов |

> **Toggle не отключает проверку.** Он переключает только режим оповещения: в обоих положениях
> условие продолжает проверяться, срабатывание пишется в журнал и показывается на дисплее.
> Полностью отключить проверку через веб-интерфейс нельзя.

> **Признак «уже показывали» — это запись в журнале, а не флаг сессии.** Как только код
> стёрт кнопкой «Очистить журнал», однократная проверка при сохраняющейся неисправности
> сработает заново — ждать перезагрузки устройства не нужно. И наоборот: перезагрузка МК
> сама по себе алерт не возвращает, потому что журнал переживает выключение питания.

### Коды алертов

| Код | Название | Описание | Параметры по умолч. |
|-----|---|---|---|
| **E01** | Engine Oil Temp High | Температура масла ДВС превысила максимум | Max: 98 °C |
| **E02** | Engine Coolant Temp High | Температура ОЖ ДВС превысила максимум | Max: 96 °C |
| **E03** | Radiator Coolant Temp High | Температура ОЖ радиатора превысила максимум | Max: 90 °C |
| **E04** | CVT Oil Temp High | Температура масла вариатора превысила максимум | Max: 100 °C |
| **E05** | Engine RPM Overspeed | Обороты двигателя превысили максимум | Max: 6500 об/мин |
| **E06** | Battery Voltage Low | Напряжение бортовой сети упало ниже минимума | Min: 11.5 В |
| **E07** | Battery Voltage High | Напряжение бортовой сети превысило максимум | Max: 15.0 В |
| **E08** | Oil Pressure Low | Напряжение датчика давления масла ниже нормы для текущих оборотов | RPM порог: 3000, Min low: 1.4 В, Min high: 2.9 В |
| **E09** | Oil-Coolant Temp Delta High | Разница температур масла и антифриза ДВС превысила порог | Max дельта: 14 °C |

### Управление алертами через веб-интерфейс

На главной странице `http://192.168.4.1` доступны два раздела:

**Журнал алертов** — список всех сработавших проверок с количеством срабатываний.
Кнопка **«Очистить журнал»** удаляет все записи и файл `/alerts.json`, а заодно снимает
запрет на повторное срабатывание: после очистки алерт поднимется снова в любом режиме.

**Настройка проверок** — карточка **«⏱ Тайминги алертов»** задаёт подтверждение и интервал
повтора сразу для всех проверок, а для каждой проверки (E01–E09) можно:
- Переключить режим срабатывания (toggle): **«При постоянной ошибке повтор раз в N сек»** или **«Однократно, пока код в журнале»**.
- Изменить пороговые значения (одно или несколько в зависимости от проверки).
- Нажать **«↺ Сброс»** на карточке, чтобы восстановить заводские параметры только этой проверки.

Изменения сохраняются в `/checks.json` и применяются немедленно без перезагрузки.

---

## 10. UDS-опрос (техническая справка)

Устройство активно опрашивает два блока управления автомобиля по протоколу **UDS (ISO 14229)** через шину CAN.

| Блок | CAN ID | Описание |
|---|---|---|
| ECM  | `0x7E0` | Блок управления двигателем |
| TCM  | `0x7E1` | Блок управления трансмиссией (вариатором) |

### Список опрашиваемых параметров

| Блок | DID | Описание |
|---|-----|---|
| ECM | `0x1201` | Обороты двигателя |
| ECM | `0x110E` | Давление наддува (турбина) |
| ECM | `0x1278` | Давление масла ДВС |
| ECM | `0x1103` | Напряжение бортовой сети |
| ECM | `0x1101` | Температура антифриза ДВС |
| ECM | `0x111F` | Температура моторного масла ДВС |
| ECM | `0x116B` | Температура антифриза радиатора |
| TCM | `0x110C` | Температура масла вариатора |

### Порядок работы планировщика

1. При старте — открывается расширенная диагностическая сессия (`0x10 0xC0`) на ECM, TCM и блоке света.
2. Отдельная задача с повышенным приоритетом каждые **30 мс** (настраивается) по кругу отправляет один
   `ReadDataByIdentifier` запрос (сервис `0x22`), независимо от отрисовки дисплея.
3. Каждые **2 секунды** — отправляется `Tester Present` (`0x3E 0x80`, без запроса ответа) на три блока
   для удержания сессии.
4. При отсутствии ответа более **1 секунды** (настраивается) значение обнуляется на дисплее.

---

## 11. Сборка из исходников (PlatformIO)

Проект собирается в WSL с помощью [PlatformIO](https://platformio.org/).

### Окружения сборки

| Окружение | Платформа | Данные | Команда сборки |
|---|---|---|---|
| `esp32` | ESP32 DEVKIT1, ST7789 | Реальный CAN | `platformio run -e esp32` |
| `esp32-mock` | ESP32 DEVKIT1, ST7789 | Имитация | `platformio run -e esp32-mock` |
| `esp32s3-wt32` | WT32-SC01 Plus, ST7796 | Реальный CAN | `platformio run -e esp32s3-wt32` |
| `esp32s3-wt32-mock` | WT32-SC01 Plus, ST7796 | Имитация | `platformio run -e esp32s3-wt32-mock` |

### Прошивка ESP32 DEVKIT1

```
platformio run -e esp32 --target upload
```

Готовый бинарник для OTA или Flash Tool:
```
.pio/build/esp32/firmware.bin
```

### Прошивка WT32-SC01 Plus (ESP32-S3)

WT32-SC01 Plus **не имеет отдельного USB-UART чипа** (CP210x / CH340). Прошивка выполняется
через встроенный USB Serial/JTAG интерфейс ESP32-S3.

**Первая прошивка — вход в режим загрузки вручную:**

1. Подключите плату к компьютеру по USB-C.
2. Зажмите кнопку **BOOT** на плате.
3. Нажмите и отпустите кнопку **RESET**.
4. Отпустите **BOOT** — плата перейдёт в режим загрузки.
5. Выполните команду:

```
platformio run -e esp32s3-wt32 --target upload
```

**Последующие прошивки** через OTA работают стандартно — кнопки не нужны.

Готовый локальный бинарник:
```
.pio/build/esp32s3-wt32/firmware.bin
```

В черновик GitHub Release WT32 добавляется комплект `bootloader_s3.bin`, `partitions_s3.bin` и
`firmware_s3.bin`. Файлы без постфикса `_s3` в релизе предназначены только для ESP32 DEVKIT1.

### Юнит-тесты

Логика, не зависящая от железа (декодер CAN, конфиг, алерты, цветовые зоны, разбор образа
прошивки), собирается под хост обычным gcc и проверяется за секунды — ни платы, ни тулчейна
xtensa для этого не нужно. В корне лежит скрипт, который сам находит PlatformIO и компилятор:

```bash
./run-tests.sh                     # все наборы
./run-tests.sh -f test_ota_image   # один набор
./run-tests.sh -vvv                # подробный вывод
```

Все, что скрипт получает, он передает в `platformio test -e native` — то же самое можно вызвать
и напрямую, если оба инструмента есть в `PATH`. Эти же тесты CI прогоняет первым шагом:
пока они не прошли, ни одна прошивка не собирается.

## 12. Лицензия

Проект предоставлен на условиях **PolyForm Noncommercial License 1.0.0**.

### ✅ Разрешено

- Использовать в личных и иных некоммерческих целях
- Копировать и изменять при сохранении текста лицензии
- Распространять в некоммерческих целях при сохранении текста лицензии

### ❌ Строго запрещено

- Использовать этот код в коммерческих устройствах
- Продавать платы или устройства с этой прошивкой
- Использовать код для оказания платных услуг

Полный текст лицензии — в файле [`LICENSE`](../LICENSE).

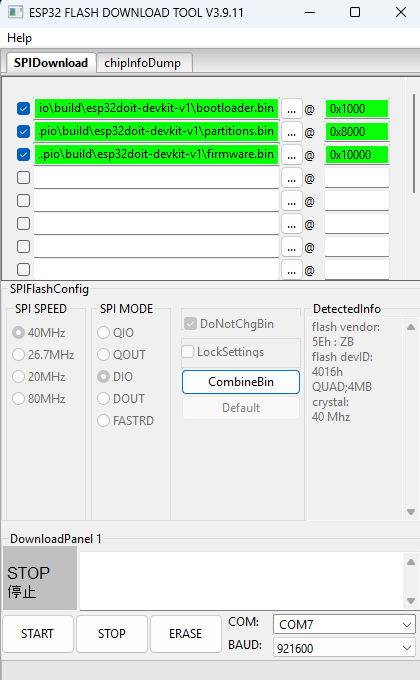
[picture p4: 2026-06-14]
docs/flash-tool.png

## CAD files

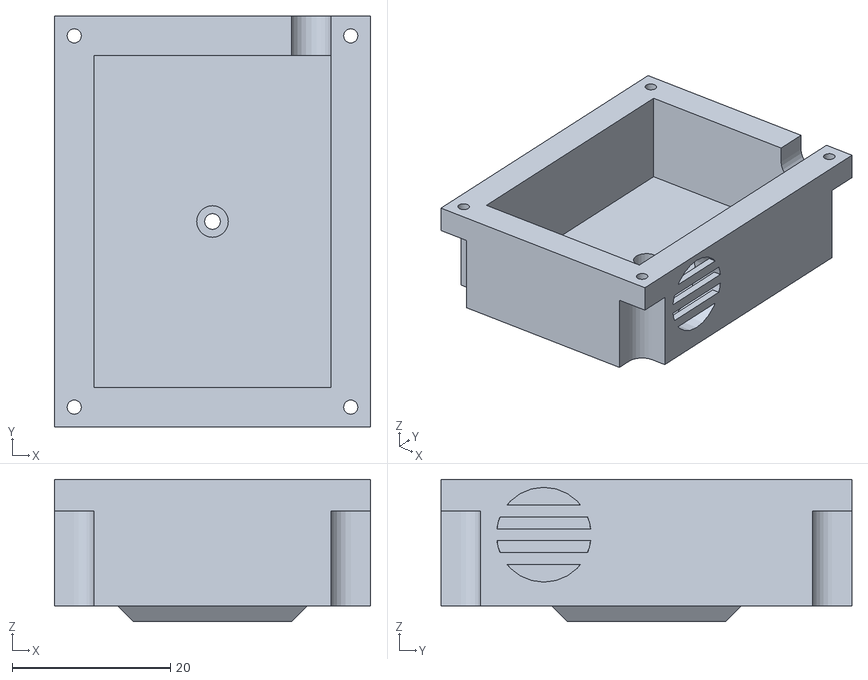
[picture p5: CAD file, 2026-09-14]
stl/display_housing_v2_1.3in/cover.stl
40.0 x 52.0 x 18.0

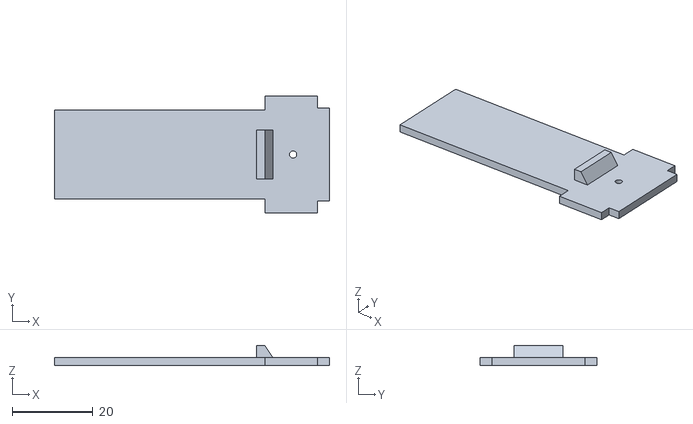
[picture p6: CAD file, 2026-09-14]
stl/mc_housing_v2/clamp.stl
68.0 x 29.0 x 5.00

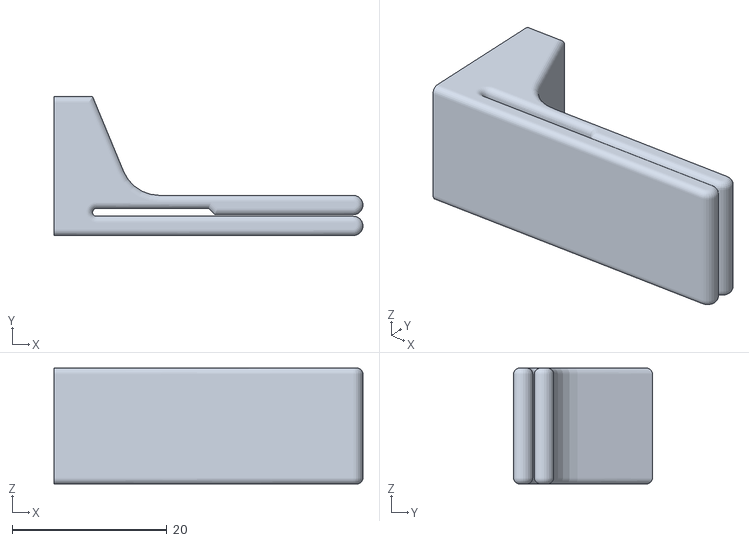
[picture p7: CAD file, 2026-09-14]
stl/display_housing_v2_1.3in/clip.stl
40.0 x 18.0 x 15.0

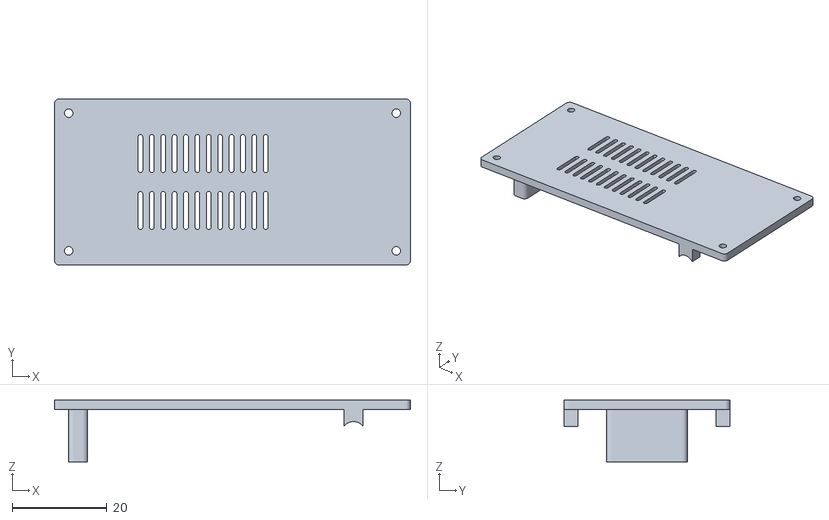
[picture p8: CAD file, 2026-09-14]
stl/mc_housing_v2/cover.stl
75.0 x 35.0 x 13.0

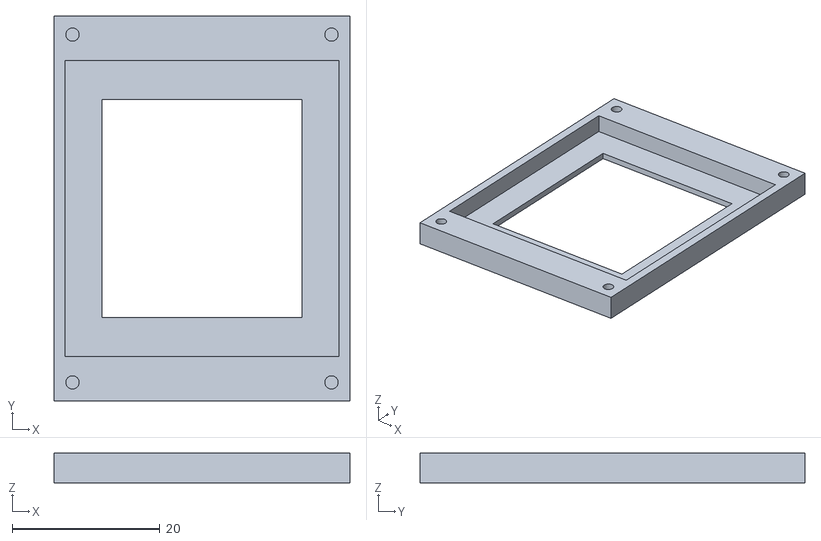
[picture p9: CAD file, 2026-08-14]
stl/display_housing_v2_1.3in/housing.stl
40.0 x 52.0 x 4.00

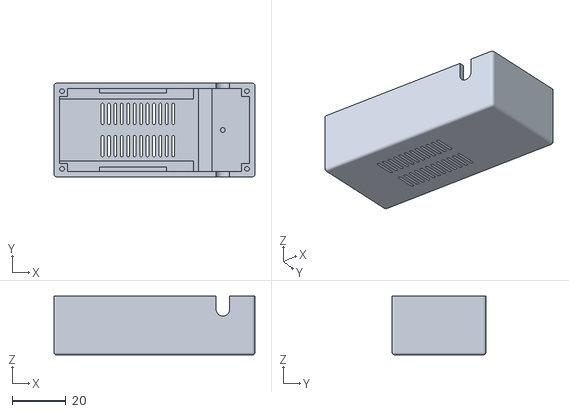
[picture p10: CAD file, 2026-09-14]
stl/mc_housing_v2/housing.stl
75.0 x 35.0 x 22.0

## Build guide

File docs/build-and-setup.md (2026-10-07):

# Сборка, подключение и первоначальная настройка

Это руководство предназначено для самостоятельной сборки устройства и разработки прошивки.
Обычному пользователю готового и установленного монитора эти действия не нужны.

## Поддерживаемые варианты

| Плата | Дисплей | Окружения PlatformIO |
|---|---|---|
| ESP32 DEVKIT1 | ST7789 240×240, SPI | `esp32`, `esp32-mock` |
| WT32-SC01 Plus ESP32-S3 | ST7796 320×480, параллельный 8-битный интерфейс | `esp32s3-wt32`, `esp32s3-wt32-mock` |

Окружения с суффиксом `-mock` имитируют данные и подходят для проверки устройства без автомобиля.

## Комплектующие

Для варианта на ESP32 DEVKIT1 нужны плата ESP32, дисплей ST7789 240×240, CAN-трансивер
WVCMCU-230 на SN65HVD230, пассивный бузер, преобразователь 12–24 В в 5 В и провода.

Для варианта на WT32-SC01 Plus отдельный дисплей не нужен. Дополнительно потребуются тот же
CAN-трансивер, пассивный бузер, преобразователь питания и провода.

Корпус для дисплея 1,3″ можно напечатать на 3D-принтере:

- [первая версия корпуса](../stl/full_v1_1.3in_display.stl)
- измененная версия: [корпус микроконтроллера](../stl/mc_housing_v2) и
  [корпус дисплея](../stl/display_housing_v2_1.3in)

## Подключение

### Дисплей ST7789 для ESP32 DEVKIT1

| Вывод дисплея | Подключение |
|---|---|
| SDA / MOSI | GPIO 23 |
| SCL / SCLK | GPIO 18 |
| RES / RST | GPIO 4 |
| DC / RS | GPIO 15 |
| BLK | GPIO 27 через резистор 500 Ом, если вывод есть |
| CS | не подключать |
| VCC | 3,3 В |
| GND | GND |

Дисплей рассчитан на 3,3 В. Подключение к 5 В может вывести его из строя.

Вывод BLK необязателен: дисплеи без него работают с той же прошивкой, но изменение яркости в
веб-интерфейсе на них не действует. Для дисплея с BLK яркость задается от 10 до 100% в разделе
«2. Системные параметры». Если по документации конкретного модуля BLK является прямым выводом питания
светодиодов, а не управляющим входом, подключайте его через транзистор или MOSFET.

### Питание WT32-SC01 Plus

Преобразователь DC-DC понижает бортовое напряжение 12–14 В до 5 В. Его выход подключается к разъему
`EXT_IO_1`: `+5 В` — к контакту 1, `GND` — к контакту 2. Контакты считаются слева направо, если
смотреть на плату так же, как на схеме ниже.

Яркость встроенной подсветки WT32-SC01 Plus регулируется прошивкой через аппаратный BL_PWM на GPIO 45.

Питание 3,3 В для WVCMCU-230 и цепи пассивного бузера берется с контакта 2 разъема `EXT_IO_2`,
второго слева. Земля CAN-трансивера и бузера подключается непосредственно к `GND` выхода DC-DC;
она является общей с землей платы.

### CAN-трансивер для обеих платформ

| Вывод WVCMCU-230 | ESP32 DEVKIT1 | WT32-SC01 Plus |
|---|---|---|
| CTX | GPIO 32 | GPIO 10, `EXT_IO_1` контакт 3 слева |
| CRX | GPIO 34 | GPIO 11, `EXT_IO_1` контакт 4 слева |
| VCC | 3,3 В | 3,3 В, `EXT_IO_2` контакт 2 слева |
| GND | GND | `GND` выхода DC-DC |
| CANH | контакт 6 OBD-II | контакт 6 OBD-II |
| CANL | контакт 14 OBD-II | контакт 14 OBD-II |

Скорость CAN — 500 кбит/с. На WT32-SC01 Plus GPIO 10 и GPIO 11 доступны на разъеме `EXT_IO_1` и
не конфликтуют со встроенным дисплеем и сенсорной панелью.

### Пассивный бузер

На ESP32 DEVKIT1 управляющий сигнал подключается к GPIO 26. На WT32-SC01 Plus он подключается к
GPIO 12, то есть к контакту 5 слева разъема `EXT_IO_1`. Питание 3,3 В берется с контакта 2 слева
разъема `EXT_IO_2`, а земля — с `GND` выхода DC-DC. Для схемы с транзистором 2N5551 используется
резистор 1 кОм.

На WT32-SC01 Plus есть встроенный I2S-усилитель и выход `SPK+/SPK-`, но самого динамика на плате нет.
Текущая прошивка этот выход не использует: звуковые сигналы воспроизводятся внешним пассивным
бузером на GPIO 12.

Схема подключения ESP32 DEVKIT1

Схема подключения WT32-SC01 Plus

## Первичная прошивка ESP32 DEVKIT1 из WSL

Плата может использовать USB-UART преобразователь CP2102, CH340 или CH9102. Передайте USB-устройство
в WSL и проверьте, что появился порт `/dev/ttyUSB0` либо `/dev/ttyACM0`:

```bash
ls -l /dev/ttyUSB* /dev/ttyACM* 2>/dev/null
```

Для прошивки без PlatformIO установите `esptool`. В релизе потребуются `bootloader.bin`,
`partitions.bin` и `firmware.bin`.

Для обычного обновления уже работающего устройства используйте веб-интерфейс и только
`firmware.bin`: OTA сохраняет установленную таблицу разделов. Не записывайте `partitions.bin`
поверх существующей установки без проверки текущей разметки и резервной копии настроек.

| Файл | Адрес |
|---|---|
| `bootloader.bin` | `0x1000` |
| `partitions.bin` | `0x8000` |
| `firmware.bin` | `0x10000` |

Команды прошивки выполняет только владелец устройства:

```bash
python3 -m esptool --chip esp32 --port /dev/ttyUSB0 --baud 921600 erase_flash
python3 -m esptool --chip esp32 --port /dev/ttyUSB0 --baud 921600 \
  write_flash --flash_mode dio --flash_freq 40m \
  0x1000 bootloader.bin 0x8000 partitions.bin 0x10000 firmware.bin
```

После завершения перезапустите плату кнопкой `EN`. Если запись не начинается, удерживайте
`BOOT` при запуске команды и отпустите ее после начала соединения.

## Первичная прошивка WT32-SC01 Plus из WSL

Для WT32-SC01 Plus в релизе используются отдельные файлы с постфиксом `_s3`. Не прошивайте в
WT32 загрузчик `bootloader.bin` от ESP32 DEVKIT1.

| Файл | Адрес |
|---|---|
| `bootloader_s3.bin` | `0x0000` |
| `partitions_s3.bin` | `0x8000` |
| `firmware_s3.bin` | `0x10000` |

Для входа в режим загрузки подключите плату по USB-C, зажмите `BOOT`, нажмите и отпустите `RESET`,
затем отпустите `BOOT`. Обычно встроенный USB Serial/JTAG появляется как `/dev/ttyACM0`.
Команды прошивки выполняет только владелец устройства:

```bash
python3 -m esptool --chip esp32s3 --port /dev/ttyACM0 --baud 460800 erase_flash
python3 -m esptool --chip esp32s3 --port /dev/ttyACM0 --baud 460800 \
  write_flash --flash_mode qio --flash_freq 80m --flash_size 16MB \
  0x0000 bootloader_s3.bin 0x8000 partitions_s3.bin 0x10000 firmware_s3.bin
```

По завершении нажмите `RESET` или переподключите USB-C.

## Сборка из исходников

Проект собирается с помощью [PlatformIO](https://platformio.org/). Установите PlatformIO Core и
убедитесь, что команда `platformio` доступна в WSL `PATH`.

```bash
platformio run
platformio run -e esp32
platformio run -e esp32s3-wt32
```

Для записи ESP32 DEVKIT1:

```bash
platformio run -e esp32 -t upload
```

Для первой записи WT32-SC01 Plus подключите USB-C, удерживайте `BOOT`, нажмите и отпустите
`RESET`, затем отпустите `BOOT` и выполните:

```bash
platformio run -e esp32s3-wt32 -t upload
```

Готовые OTA-образы находятся в `.pio/build/<окружение>/firmware.bin`.

## Юнит-тесты

Хостовые тесты не требуют платы или Xtensa toolchain. Из корня проекта выполните:

```bash
./run-tests.sh
./run-tests.sh -f test_ota_image
```

Либо вызовите PlatformIO напрямую:

```bash
platformio test -e native
```

## Обновление готового устройства

После первичной прошивки обновления устанавливаются без кабеля. Подключитесь к сети
`QX50Monitoring`, откройте [http://192.168.4.1](http://192.168.4.1), перейдите к разделу
обновления и загрузите совместимый `firmware.bin`. Не отключайте питание до завершения записи и
автоматической перезагрузки.

Подробности об OTA-слотах, формате прошивки и работе системы приведены в
[технических нюансах](technical-details.md).

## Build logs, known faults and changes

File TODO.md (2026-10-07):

# TODO

Здесь перечислены только незакрытые задачи. Выполненные изменения разметки, CI и документации
в этот файл не входят.

## P0 — проверить OTA на обеих разметках DEVKIT1 перед релизом

### Проблема

На устройствах могут быть установлены две таблицы разделов ESP32 4 МБ:

- классическая: два OTA-слота по 1,75 МиБ и LittleFS 448 КиБ;
- временно выпускавшаяся увеличенная: два OTA-слота по 1,875 МиБ и LittleFS 192 КиБ.

Текущая сборка снова использует классическую таблицу. OTA не записывает `partitions.bin`, а прошивка
получает адреса и размеры разделов из таблицы самого устройства, поэтому один `firmware.bin` должен
работать на обеих разметках. Это подтверждено кодом и сборкой, но еще не проверено на физическом
DEVKIT1. Ошибка здесь может привести к неудачной загрузке, потере доступа к настройкам или
невозможности вернуться во второй OTA-слот.

### Что проверить

- [ ] Подготовить DEVKIT1 с классической разметкой и DEVKIT1 с увеличенной разметкой
- [ ] Перед испытанием сохранить конфигурацию и содержимое журналов на каждом устройстве
- [ ] Загрузить один и тот же `firmware.bin` через веб-интерфейс, не записывая `partitions.bin`
- [ ] На каждой разметке последовательно обновить оба OTA-слота и проверить загрузку из каждого
- [ ] Проверить ручное переключение между слотами и возврат к предыдущему образу
- [ ] После обновления и нескольких перезагрузок сравнить настройки, журнал алертов и историю сбросов
- [ ] Отдельно подтвердить запись файлов при LittleFS 192 КиБ, поскольку это худший доступный объем
- [ ] Убедиться, что веб-интерфейс правильно показывает размер, адрес, версию и активность обоих слотов

### Критерий готовности

Один `firmware.bin` без замены таблицы разделов загружается, работает и откатывается на обеих
разметках; настройки и журналы сохраняются. До этого проверку нельзя считать завершенной, даже если
юнит-тесты и сборка проходят.

## P0 — защитить смену разметки в Kanvex Service Tool

### Проблема

Релизный USB-комплект содержит классический `partitions.bin`. Если записать его поверх устройства с
увеличенной разметкой, изменятся адрес и размер LittleFS. Обычная прошивка через Tool сейчас не
выполняет безопасную миграцию данных и не должна незаметно заменять установленную таблицу.

### Что реализовать в `~/kanvex/tool`

- [ ] Перед любой записью прочитать установленную таблицу разделов и сравнить ее с целевой
- [ ] При совпадении разрешать обычную прошивку по существующему сценарию
- [ ] При различии останавливать обычную прошивку до записи и показывать понятное описание риска
- [ ] В `--dry-run` выводить обнаруженную и целевую разметки, планируемые действия и причину отказа
- [ ] Для осознанной миграции сделать отдельный явно подтверждаемый сценарий, а не скрытый флаг
- [ ] Перед миграцией сохранять доступные настройки и журналы, после записи восстанавливать их
- [ ] Проверять корректный выбор загрузочного слота и успешный запуск после миграции
- [ ] Добавить тесты для совпадающих, различающихся, поврежденных и нечитаемых таблиц разделов
- [ ] Обновить инструкции USB-восстановления и состав релизного комплекта после реализации

### Критерий готовности

Обычная операция Tool никогда не меняет разметку молча. Миграция выполняется только отдельным
сценарием с подтверждением, резервной копией, восстановлением данных и проверкой загрузки.

## P1 — проверить OBD-II на автомобиле

### Проблема

Декодирование и планировщик фонового OBD-II-опроса покрыты юнит-тестами, но фактический набор
поддерживаемых PID, стабильность ответов и совместная работа с основным UDS-опросом зависят от
автомобиля и еще не подтверждены. Слишком частые или конфликтующие запросы могут увеличить время
обновления основных метрик либо вызвать пропуски диагностических ответов.

### Что проверить

- [ ] Записать обнаруженные диапазоны поддерживаемых PID и сравнить их после повторного запуска
- [ ] Поочередно включить поддерживаемые PID и проверить значения, единицы измерения и частоту обновления
- [ ] Сравнить счетчик подтвержденных DTC из PID `0x01` с показаниями проверенного сканера
- [ ] Сравнить частоту и стабильность основных UDS-метрик при выключенном и включенном OBD-II-опросе
- [ ] Убедиться, что не растут счетчики ошибок CAN, bus-off, восстановления шины и пропущенных ответов
- [ ] Проверить работу при заглушенном двигателе, после запуска и на прогретом двигателе
- [ ] Сохранить наблюдения и обнаруженные неподдерживаемые либо неверно декодируемые PID

### Критерий готовности

Фоновый OBD-II-опрос возвращает правдоподобные данные и не ухудшает надежность или частоту основного
UDS-опроса. Все расхождения либо исправлены, либо явно задокументированы.

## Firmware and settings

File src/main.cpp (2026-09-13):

#include <atomic>
#include <math.h>

#include <Arduino.h>
#include <freertos/FreeRTOS.h>
#include <freertos/semphr.h>
#include <freertos/task.h>

#include "CanBusManager.h"
#include "ConfigManager.h"
#include "DiagnosticMode.h"
#include "DiagnosticSelection.h"
#include "WebManager.h"
#include "BuzzerController.h"
#include "AlertManager.h"
#include "BuildInfo.h"
#include "OtaImage.h"
#include "ObdPidCatalog.h"
#include "ObdPollPlan.h"
#include "ResetHistory.h"
#include "Version.h"

// Выбор менеджера дисплея в зависимости от целевой платформы
#if defined(DISPLAY_WT32_S3)
#include "DisplayManagerWT32.h"
DisplayManagerWT32 display;
#else
#include "DisplayManager.h"
DisplayManager     display;
#endif

// Вернуть значение из CAN если оно свежее (обновлено не позднее stale_ms мс из конфига),
// иначе вернуть 0. Таймстамп 0 означает «ни разу не получено» — тоже 0
static float can_value(float value, uint32_t ts)
{
    if (ts == 0) return 0.0f;
    uint32_t stale_ms = static_cast<uint32_t>(config.get("system", "stale_ms"));
    return (millis() - ts <= stale_ms) ? value : 0.0f;
}

WebManager       web;
BuzzerController buzzer;

// =============================================================================
// Веб-сервер в отдельной задаче
// =============================================================================
//
// Конечный автомат WebServer делает один шаг за вызов handleClient(): принять
// сокет, дождаться запроса, разобрать его, ответить. Пока эти шаги висели в
// loop(), их темп задавала самая медленная часть цикла — отрисовка дисплея.
// В своей задаче на ядре 0 шаги идут раз в миллисекунду независимо от loop().
//
// Плата за это — общее состояние (config, alert_manager, can_metrics) теперь
// читается и пишется из двух задач. Мьютекс ниже разводит доступ: веб-задача
// держит его на время handleClient(), loop() — на время своей итерации.
// Без мьютекса POST /config, перестраивающий JsonDocument, мог бы совпасть
// с config.get() из loop() и уронить прошивку

// Стек веб-задачи: обработчикам нужны ArduinoJson, String и буферы OTA
static constexpr uint32_t WEB_TASK_STACK_BYTES = 8192;

// Ядро для веб-задачи: loopTask Arduino работает на ядре 1
static constexpr BaseType_t WEB_TASK_CORE = 0;

// Приоритет как у loopTask — веб не должен вытеснять основной цикл
static constexpr UBaseType_t WEB_TASK_PRIORITY = 1;

// Мьютекс общего состояния между loop() и веб-задачей
static SemaphoreHandle_t s_state_mutex = nullptr;

// true после успешного запуска веб-задачи. Если задачу или мьютекс создать
// не удалось, HTTP остается в loop() — интерфейс работает медленно, но работает
static bool s_web_in_task = false;

// Захват и освобождение общего состояния. Пока мьютекса нет (setup до запуска
// веб-задачи) вызовы безопасно превращаются в no-op
static inline void state_lock()
{
    if (s_state_mutex != nullptr) xSemaphoreTake(s_state_mutex, portMAX_DELAY);
}

static inline void state_unlock()
{
    if (s_state_mutex != nullptr) xSemaphoreGive(s_state_mutex);
}

static void web_task(void *)
{
    for (;;) {
        state_lock();
        web.handle();
        state_unlock();

        // Пауза обязательна: без нее задача с приоритетом loopTask не пускает
        // к работе idle-задачу ядра 0 и срабатывает Task WDT. Один тик FreeRTOS
        // (1 мс) на шаг автомата — на порядок быстрее прежней привязки к loop()
        vTaskDelay(1);
    }
}

// Запустить HTTP-сервер в отдельной задаче. Вызывать в конце setup(), когда
// конфиг, журнал алертов и CAN уже инициализированы: обработчики читают их
// сразу после первого же запроса
static void web_task_start()
{
    s_state_mutex = xSemaphoreCreateMutex();
    if (s_state_mutex == nullptr) {
        Serial.println("[Web] Мьютекс не создан — сервер остается в loop()");
        return;
    }

    if (xTaskCreatePinnedToCore(web_task, "web", WEB_TASK_STACK_BYTES, nullptr,
                                WEB_TASK_PRIORITY, nullptr, WEB_TASK_CORE) != pdPASS) {
        vSemaphoreDelete(s_state_mutex);
        s_state_mutex = nullptr;
        Serial.println("[Web] Задача не создана — сервер остается в loop()");
        return;
    }

    s_web_in_task = true;
    Serial.printf("[Web] Сервер вынесен в отдельную задачу на ядре %d\r\n",
                  static_cast<int>(WEB_TASK_CORE));
}

// =============================================================================
// Планировщик UDS-опроса
// =============================================================================

// Адреса блоков управления
static constexpr uint32_t ECM_ID = 0x7E0; // Блок управления двигателем
static constexpr uint32_t TCM_ID = 0x7E1; // Блок управления трансмиссией
static constexpr uint32_t LIGHT_MODULE_ID = 0x743; // Блок состояния освещения
static constexpr uint32_t LIGHT_RESPONSE_ID = 0x763; // Ответ блока состояния освещения
static constexpr uint16_t LIGHT_STATUS_DID = 0x0E07;

// Команда открытия расширенной диагностической сессии (0x10 0xC0)
static const uint8_t CMD_SESSION_OPEN[8] = { 0x02, 0x10, 0xC0, 0x00, 0x00, 0x00, 0x00, 0x00 };

// Команда поддержания диагностической сессии (Tester Present, 0x3E 0x80 — без ответа)
static const uint8_t CMD_TESTER_PRESENT[8] = { 0x02, 0x3E, 0x80, 0x00, 0x00, 0x00, 0x00, 0x00 };

// Описание одного параметра для циклического опроса
struct PollEntry {
    uint32_t ecu_id; // Адрес блока: ECM_ID или TCM_ID
    uint16_t did;    // Data Identifier (UDS Service 0x22)
};

// Список параметров для опроса (строго по заданному порядку)
static constexpr PollEntry POLL_LIST[] = {
    { ECM_ID, 0x1201 }, // Обороты двигателя
    { ECM_ID, 0x110E }, // Давление наддува (турбина)
    { ECM_ID, 0x1278 }, // Давление масла ДВС
    { ECM_ID, 0x1103 }, // Напряжение бортовой сети
    { ECM_ID, 0x1101 }, // Температура ОЖ ДВС
    { ECM_ID, 0x111F }, // Температура масла ДВС
    { ECM_ID, 0x116B }, // Температура ОЖ радиатора
    { TCM_ID, 0x110C }, // Температура масла вариатора
};
static constexpr uint8_t POLL_COUNT = sizeof(POLL_LIST) / sizeof(POLL_LIST[0]);

// Интервал отправки Tester Present (мс)
static constexpr uint32_t TESTER_PRESENT_INTERVAL_MS = 2000;
static constexpr uint32_t LIGHT_POLL_INTERVAL_MS = 1000;
static constexpr uint32_t OBD_POLL_INTERVAL_MS = 1000;
static constexpr uint32_t DEFAULT_OBD_REQUEST_SPACING_MS = 5;
static constexpr uint32_t OBD_DISCOVERY_TIMEOUT_MS = 1000;
static constexpr uint8_t OBD_POLL_COUNT = DIAGNOSTIC_MAX_PID;
static uint8_t s_obd_poll_list[OBD_POLL_COUNT];

// Текущий индекс в списке опроса
static uint8_t  s_poll_idx       = 0;

// Таймер между отправками запросов параметров
static std::atomic<uint32_t> s_last_poll_ms{0};

// Интервал опроса кешируется основным циклом под мьютексом конфига
static std::atomic<uint32_t> s_poll_interval_ms{30};

// Результат измерения RPM передается из задачи опроса в основной цикл
static std::atomic<uint32_t> s_rpm_request_ts{0};
static std::atomic<uint32_t> s_rpm_poll_time_ms{0};
static std::atomic<uint32_t> s_rpm_poll_time_ts{0};

// true после успешного запуска отдельной задачи UDS-опроса
static bool s_poll_in_task = false;

static constexpr uint32_t POLL_TASK_STACK_BYTES = 4096;
static constexpr BaseType_t POLL_TASK_CORE = 1;
static constexpr UBaseType_t POLL_TASK_PRIORITY = 2;

// Таймер отправки Tester Present
static uint32_t s_last_tp_ms     = 0;

// Таймер проверки состояния освещения
static uint32_t s_last_light_poll_ms = 0;
static ObdPollPlan s_obd_poll_plan(obd_pid_catalog, s_obd_poll_list, OBD_POLL_COUNT,
                                   OBD_POLL_INTERVAL_MS, DEFAULT_OBD_REQUEST_SPACING_MS);
static bool s_diagnostic_session_open = false;
static uint32_t s_obd_discovery_sent_ms = 0;

// Принять ответы штатного мониторинга и завершить ISO-TP обмен с блоком света
static void can_handle_monitor_frame(const CanFrame &frame)
{
    can_print_frame(frame);
    obd_pid_catalog.accept(frame);

    if (frame.id != LIGHT_RESPONSE_ID || frame.dlc < 7) {
        return;
    }

    const uint8_t *d = frame.data;
    const bool is_first_frame = (d[0] & 0xF0) == 0x10;
    const uint16_t payload_length = (static_cast<uint16_t>(d[0] & 0x0F) << 8) | d[1];
    const bool is_light_status = d[2] == 0x62 && d[3] == static_cast<uint8_t>(LIGHT_STATUS_DID >> 8) &&
                                 d[4] == static_cast<uint8_t>(LIGHT_STATUS_DID & 0xFF);
    if (!is_first_frame || payload_length < 5 || !is_light_status) {
        return;
    }

    // Разрешить блоку передать оставшиеся Consecutive Frame
    const uint8_t flow_control[8] = { 0x30, 0x00, 0x00, 0xFF, 0xFF, 0xFF, 0xFF, 0xFF };
    can_bus.send_frame(LIGHT_MODULE_ID, flow_control, 8);

    // Второй байт данных DID: 0x0C = OFF, 0x1C = ON, меняется бит 0x10
    Serial.printf("[Light] %s raw=0x%02X\r\n", can_metrics.exterior_light_on ? "ON" : "OFF", d[6]);
}

static bool obd_send_request(uint8_t pid)
{
    const uint8_t req[8] = {0x02, 0x01, pid, 0, 0, 0, 0, 0};
    return can_bus.try_send_frame(ECM_ID, req, 8);
}

// Сформировать и отправить UDS ReadDataByIdentifier (Service 0x22) для заданного DID
static void poll_send_request(uint32_t ecu_id, uint16_t did)
{
    // Формат: [0x03][0x22][DID_HI][DID_LO][00 00 00 00]
    uint8_t req[8] = {
        0x03,
        0x22,
        static_cast<uint8_t>(did >> 8),
        static_cast<uint8_t>(did & 0xFF),
        0x00, 0x00, 0x00, 0x00
    };
    can_bus.send_frame(ecu_id, req, 8);
}

// Открыть расширенную диагностическую сессию на опрашиваемых блоках
static void poll_open_session()
{
    can_bus.send_frame(ECM_ID, CMD_SESSION_OPEN, 8);
    delay(30); // Небольшая пауза между кадрами при инициализации
    can_bus.send_frame(TCM_ID, CMD_SESSION_OPEN, 8);
    delay(30);
    can_bus.send_frame(LIGHT_MODULE_ID, CMD_SESSION_OPEN, 8);
    Serial.println("[Poll] Расширенная сессия открыта (ECM + TCM + LIGHT)");
}

// Отправить Tester Present на опрашиваемые блоки
static void poll_tester_present()
{
    can_bus.send_frame(ECM_ID, CMD_TESTER_PRESENT, 8);
    can_bus.send_frame(TCM_ID, CMD_TESTER_PRESENT, 8);
    can_bus.send_frame(LIGHT_MODULE_ID, CMD_TESTER_PRESENT, 8);
}

// Обработать один шаг планировщика из отдельной задачи или резервно из loop()
static void poll_handle()
{
    uint32_t now = millis();

    if (!s_diagnostic_session_open) {
        poll_open_session();
        s_diagnostic_session_open = true;
        s_last_poll_ms.store(millis(), std::memory_order_relaxed);
        return;
    }

    // Tester Present каждые 2 секунды
    if (now - s_last_tp_ms >= TESTER_PRESENT_INTERVAL_MS) {
        s_last_tp_ms = now;
        poll_tester_present();
    }

    // Частый опрос нужен для быстрого переключения яркости после включения света
    if (now - s_last_light_poll_ms >= LIGHT_POLL_INTERVAL_MS) {
        s_last_light_poll_ms = now;
        poll_send_request(LIGHT_MODULE_ID, LIGHT_STATUS_DID);
    }

    // Циклический опрос параметров с паузой из конфига (system.poll_interval_ms)
    const uint32_t poll_interval_ms = s_poll_interval_ms.load(std::memory_order_relaxed);
    if (now - s_last_poll_ms.load(std::memory_order_relaxed) >= poll_interval_ms) {
        s_last_poll_ms.store(now, std::memory_order_relaxed);

        const PollEntry &entry = POLL_LIST[s_poll_idx];
        poll_send_request(entry.ecu_id, entry.did);

        // Вычисляем период обновления RPM (время между двумя последовательными отправками запроса)
        // rpm_poll_time показывает реальный интервал обновления данных оборотов = poll_interval_ms * POLL_COUNT
        if (entry.ecu_id == ECM_ID && entry.did == 0x1201) {
            const uint32_t previous_request_ts = s_rpm_request_ts.load(std::memory_order_relaxed);
            s_rpm_request_ts.store(now, std::memory_order_relaxed);
            if (previous_request_ts != 0) {
                s_rpm_poll_time_ms.store(now - previous_request_ts, std::memory_order_relaxed);
                s_rpm_poll_time_ts.store(now, std::memory_order_release);
            }
        }

        s_poll_idx = (s_poll_idx + 1) % POLL_COUNT;
    }
}

// Фоновый OBD-опрос остается в основном цикле вместе с приемом и декодированием CAN
static void obd_poll_handle()
{
    const uint32_t now = millis();

    if (!diagnostic_mode_active(now)) return;

    if (!obd_pid_catalog.complete()) {
        const uint8_t next_base = obd_pid_catalog.next_query_base();
        const bool timed_out = now - s_obd_discovery_sent_ms >= OBD_DISCOVERY_TIMEOUT_MS;
        if (timed_out && obd_send_request(next_base)) {
            s_obd_discovery_sent_ms = now;
        }
        return;
    }

    const uint32_t last_poll_ms = s_last_poll_ms.load(std::memory_order_relaxed);
    const uint32_t poll_interval_ms = s_poll_interval_ms.load(std::memory_order_relaxed);
    const bool primary_due = now - last_poll_ms >= poll_interval_ms;
    const int16_t pid = s_obd_poll_plan.next(now, primary_due);
    if (pid < 0) return;
    const bool sent = obd_send_request(static_cast<uint8_t>(pid));
    s_obd_poll_plan.complete_send(sent);
}

static void poll_task(void *)
{
    for (;;) {
        poll_handle();
        vTaskDelay(1);
    }
}

static void poll_task_start()
{
    if (xTaskCreatePinnedToCore(poll_task, "uds-poll", POLL_TASK_STACK_BYTES, nullptr,
                                POLL_TASK_PRIORITY, nullptr, POLL_TASK_CORE) != pdPASS) {
        Serial.println("[Poll] Задача не создана — опрос остается в loop()");
        return;
    }

    s_poll_in_task = true;
    Serial.printf("[Poll] Опрос вынесен в отдельную задачу на ядре %d\r\n",
                  static_cast<int>(POLL_TASK_CORE));
}

// =============================================================================

void setup()
{
#ifdef DID_HOOK_MODE
    Serial.begin(DID_HOOK_SERIAL_BAUD);
#else
    Serial.begin(115200);
#endif
    Serial.printf("[Boot] Firmware %s, env %s\r\n", FW_VERSION, BUILD_ENV);
#ifdef DID_HOOK_MODE
    Serial.println("=== Infiniti QX50 J55 DID Hook ===");

    config.init();
    reset_history.init();
    display.init(FW_VERSION);
    display.show_alert("HOOK", "DID\nHOOK MODE\nSERIAL LOG");
    web.begin();
    alert_manager.init();

    can_bus.on_frame(can_print_did_hook_frame);
    can_bus.init();
    web_task_start();

    Serial.printf("[HOOK] Пассивный перехват всех CAN ID, Serial %lu\r\n",
                  static_cast<unsigned long>(DID_HOOK_SERIAL_BAUD));
    Serial.printf("[HOOK] Firmware marker: %s\r\n", FW_IMAGE_TAG);
    Serial.printf("[Web] Адрес веб-интерфейса: http://%s\r\n", web.get_ip().c_str());
    Serial.println("=====================================");
    return;
#else
    Serial.println("=== Infiniti QX50 J55 Monitoring ===");

    for (uint16_t pid = 1; pid <= OBD_POLL_COUNT; ++pid) {
        s_obd_poll_list[pid - 1] = static_cast<uint8_t>(pid);
    }
    s_obd_poll_plan.set_enabled(diagnostic_selection.pid_flags());

    config.init();
    reset_history.init();

    const uint32_t configured_poll_interval =
        static_cast<uint32_t>(config.get("system", "poll_interval_ms"));
    if (configured_poll_interval > 0) {
        s_poll_interval_ms.store(configured_poll_interval, std::memory_order_relaxed);
    }
    s_obd_poll_plan.set_request_spacing(
        static_cast<uint32_t>(config.get("system", "obd_request_spacing_ms")));

    // Версия прошивки (FW_VERSION из include/Version.h) — отображается внизу дисплея
    display.init(FW_VERSION);
    web.begin();

    // Инициализация менеджера алертов (после монтирования LittleFS в config.init())
    alert_manager.init();

#ifndef USE_MOCK_DATA
    // Инициализация CAN-шины (SN65HVD230 / WVCMCU-230)
    can_bus.on_frame(can_handle_monitor_frame);
    can_bus.init();

    // Инициализируем таймеры планировщика
    s_last_poll_ms.store(millis(), std::memory_order_relaxed);
    s_last_tp_ms   = millis();
    s_last_light_poll_ms = millis();
#endif

    // Все общее состояние готово — можно пускать HTTP-обработчики в свою задачу
    web_task_start();

#ifndef USE_MOCK_DATA
    poll_task_start();
#endif

    Serial.printf("[Web] Адрес веб-интерфейса: http://%s\r\n", web.get_ip().c_str());
    Serial.println("=====================================");

    // Звук загрузки, как у BIOS
    buzzer.hello();
#endif
}

void loop()
{
#ifdef DID_HOOK_MODE
    if (!s_web_in_task) {
        web.handle();
    }

    can_bus.handle();

    static uint32_t s_last_hook_status_ms = 0;
    const uint32_t now = millis();
    if (now - s_last_hook_status_ms >= 2000) {
        s_last_hook_status_ms = now;
        Serial.printf("[HOOK] CAN state=%s RX=%lu errors=%lu bus_off=%lu\r\n",
                      can_bus.state_name(),
                      static_cast<unsigned long>(can_bus.received_count()),
                      static_cast<unsigned long>(can_bus.error_count()),
                      static_cast<unsigned long>(can_bus.bus_off_count()));
    }

    delay(1);
#else
    // Общее состояние делим с веб-задачей — держим мьютекс всю итерацию.
    // Итерация короткая (десятки микросекунд, раз в 100 мс — отрисовка),
    // поэтому веб-задача почти никогда не ждет на этом мьютексе
    state_lock();

    // Ждем триггера для бузера
    buzzer.update();

    // Обрабатываем HTTP запросы, если веб-задачу поднять не удалось
    if (!s_web_in_task) {
        web.handle();
    }

    // Читаем фреймы с CAN-шины автомобиля (без delay — чтобы не терять фреймы)
    can_bus.handle();

#ifndef USE_MOCK_DATA
    const uint32_t configured_poll_interval =
        static_cast<uint32_t>(config.get("system", "poll_interval_ms"));
    if (configured_poll_interval > 0) {
        s_poll_interval_ms.store(configured_poll_interval, std::memory_order_relaxed);
    }
    s_obd_poll_plan.set_request_spacing(
        static_cast<uint32_t>(config.get("system", "obd_request_spacing_ms")));

    // Переносим измеренное задачей значение в общее состояние под мьютексом
    const uint32_t measured_poll_time_ts = s_rpm_poll_time_ts.load(std::memory_order_acquire);
    const uint32_t measured_poll_time_ms = s_rpm_poll_time_ms.load(std::memory_order_relaxed);
    if (measured_poll_time_ts != 0 && measured_poll_time_ts != can_metrics.rpm_poll_time_ts) {
        can_metrics.rpm_request_ts = s_rpm_request_ts.load(std::memory_order_relaxed);
        can_metrics.rpm_poll_time = static_cast<float>(measured_poll_time_ms) / 1000.0f;
        can_metrics.rpm_poll_time_ts = measured_poll_time_ts;
    }

    // Если отдельную задачу создать не удалось, сохраняем прежний опрос через loop()
    if (!s_poll_in_task) {
        poll_handle();
    }
    obd_poll_handle();
#endif

    // Проверяем алерты раз в 200 мс
    static uint32_t s_last_alert_check = 0;
    if (millis() - s_last_alert_check >= 200) {
        s_last_alert_check = millis();
        alert_manager.update(can_metrics);
    }

    // Обновляем дисплей не чаще 10 раз в секунду, без блокирующего delay
    static uint32_t s_last_display = 0;
    if (millis() - s_last_display >= 100) {
        s_last_display = millis();

        float t = millis() / 3000.0f;

        // Имитация данных с датчиков автомобиля Infiniti для проверки отображения
        float mock_transmission = 80.0f + sinf(t * 2.0f) * 40.0f;

        // Обороты двигателя: 750..6000 об/мин
        float mock_rpm = 750.0f +
            (sinf(t * 2.1f) * 0.5f + 0.5f) * (6000.0f - 750.0f);

        // Напряжение датчика давления масла: 1.3..3.5 В
        float mock_oil_pressure =
            1.3f + (sinf(t * 2.3f) * 0.5f + 0.5f) * (3.5f - 1.3f);

        // Давление наддува (Вольты): 0.50..4.50 В
        // sinf даёт -1..+1 → центр 2.50, амплитуда 2.00 → диапазон 0.5..4.5
        float mock_boost = 2.50f + sinf(t * 1.9f) * 2.00f;

        // Период обновления RPM: 0.01..0.60 с — имитация на основе синуса
        float mock_poll_time = 0.01f + (sinf(t * 2.5f) * 0.5f + 0.5f) * (0.60f - 0.01f);

        // Вольтаж бортовой сети: 11.0..15.0 Вольт
        // sinf дает -1..+1 → центр 13.0V, амплитуда 2.0V → диапазон 11.0..15.0
        float mock_battery_voltage = 13.0f + sinf(t * 1.8f) * 2.0f;

#ifdef USE_MOCK_DATA
        // --- МОКИ: имитация всех датчиков для отладки отображения ---
        float   coolant          = 85.0f + sinf(t * 2.0f) * 20.0f;
        float   oil              = 90.0f + sinf(t * 2.2f) * 20.0f;
        float   coolant_r        = 50.0f + sinf(t * 1.7f) * 70.0f;
        float   rpm              = mock_rpm;
        float   oil_pressure     = mock_oil_pressure;
        float   boost            = mock_boost;
        float   poll_time        = mock_poll_time;
        float   battery_voltage  = mock_battery_voltage;
        float   transmission     = mock_transmission;

        // Записываем мок-данные в can_metrics — AlertManager читает именно оттуда
        {
            uint32_t ts = millis();
            can_metrics.engine_oil           = oil;
            can_metrics.engine_oil_ts        = ts;
            can_metrics.engine_coolant       = coolant;
            can_metrics.engine_coolant_ts    = ts;
            can_metrics.radiator_coolant     = coolant_r;
            can_metrics.radiator_coolant_ts  = ts;
            can_metrics.cvt_temp             = transmission;
            can_metrics.cvt_temp_ts          = ts;
            can_metrics.engine_rpm           = rpm;
            can_metrics.engine_rpm_ts        = ts;
            can_metrics.battery_voltage      = battery_voltage;
            can_metrics.battery_voltage_ts   = ts;
            can_metrics.oil_pressure_volt    = oil_pressure;
            can_metrics.oil_pressure_volt_ts = ts;
            can_metrics.turbo_boost_volt     = boost;
            can_metrics.turbo_boost_volt_ts  = ts;
        }
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

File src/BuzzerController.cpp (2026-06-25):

#include "BuzzerController.h"

#include <Arduino.h>

// LEDC-канал для бузера (0..15 доступны на ESP32; 0 не занят TFT_eSPI)
static constexpr uint8_t BUZZER_LEDC_CHANNEL = 0;

// Частота и разрядность ШИМ
static constexpr uint32_t BUZZER_LEDC_FREQ_HZ  = 2700;
static constexpr uint8_t  BUZZER_LEDC_BITS      = 10;

static bool s_ledc_attached = false;

// Инициализация LEDC один раз — предотвращает ошибку "LEDC is not initialized",
// которую вызывает noTone() через ledcDetachPin() в Core 2.x.
// После этого используем только ledcWriteTone/ledcWrite без detach.
static void buzzer_attach()
{
    if (!s_ledc_attached) {
        ledcSetup(BUZZER_LEDC_CHANNEL, BUZZER_LEDC_FREQ_HZ, BUZZER_LEDC_BITS);
        ledcAttachPin(CAN_BUZZER_PIN, BUZZER_LEDC_CHANNEL);
        s_ledc_attached = true;
    }
}

static void buzzer_tone(uint32_t freq)
{
    buzzer_attach();
    ledcWriteTone(BUZZER_LEDC_CHANNEL, freq);
}

static void buzzer_off()
{
    // Duty = 0 → тишина, канал остаётся прикреплённым
    if (s_ledc_attached) {
        ledcWrite(BUZZER_LEDC_CHANNEL, 0);
    }
}

void BuzzerController::trigger_alert()
{
    if (!is_playing_) {
        is_playing_ = true;
        step_ = 0;
        last_time_ = millis();
    }
}

void BuzzerController::update()
{
    if (!is_playing_) {
        return;
    }

    unsigned long now = millis();

    // 1-й писк (Частота 2700 Гц, длительность 60 мс)
    if (step_ == 0) {
        buzzer_tone(2700);
        step_ = 1;
        last_time_ = now;
    }
    // Пауза после 1-го писка (50 мс)
    else if (step_ == 1 && (now - last_time_ >= 60)) {
        buzzer_off();
        step_ = 2;
        last_time_ = now;
    }
    // 2-й писк (60 мс)
    else if (step_ == 2 && (now - last_time_ >= 50)) {
        buzzer_tone(2700);
        step_ = 3;
        last_time_ = now;
    }
    // Пауза после 2-го писка (50 мс)
    else if (step_ == 3 && (now - last_time_ >= 60)) {
        buzzer_off();
        step_ = 4;
        last_time_ = now;
    }
    // 3-й писк (60 мс)
    else if (step_ == 4 && (now - last_time_ >= 50)) {
        buzzer_tone(2700);
        step_ = 5;
        last_time_ = now;
    }
    // Выключение звука
    else if (step_ == 5 && (now - last_time_ >= 60)) {
        buzzer_off();
        is_playing_ = false;
    }
}

void BuzzerController::hello()
{
    buzzer_tone(2500);
    delay(100);
    buzzer_off();
}

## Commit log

2026-06-13 CP2102 driver manual
2026-06-14 Added WebManager and partitions
    [partitions.csv]
2026-06-14 Added CanBusManager
2026-06-16 Added OTA
    [partitions.csv]
2026-06-17 esp32-mock & esp32 evns
2026-06-18 Remove print CAN data
2026-06-18 Gear color
2026-06-18 Blue color for ZERO & UI bug fix
    [DisplayManager.cpp, main.cpp]
2026-06-25 Check for mock data & UI bug fix
    [main.cpp]
2026-06-26 Web UI bug fix
    [AlertManager.cpp]
2026-07-03 Added STLs
    [display_housing.stl, mc_housing.stl]
2026-07-15 Fixed 3.3V
2026-07-15 New diagram - fixed 3.3V
2026-07-26 Atomic filesystem writes, config defaults fallback, CI workflow
    Storage reliability:
    - Write /config.json, /checks.json and /alerts.json to a temporary file
    and rename it over the target, so a power loss mid-write leaves the
    previous file intact instead of truncated JSON (new fs_write_json_atomic
    in FsUtils)
    - Verify the written byte count against measureJson to catch a write cut
    short by a full partition
    - ConfigManager::get/get_str now fall back to factory defaults instead of
    returning 0 when a field is missing, so a damaged config no longer
    silently zeroes every threshold
    - AlertManager rewrites /checks.json only when it is missing, corrupt or
    incomplete, instead of on every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
    [AlertManager.cpp, CanBusManager.cpp, ConfigManager.cpp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]
2026-07-26 Run firmware builds in parallel and switch CI job names to English
2026-08-05 Add OTA slot switching and fetch update binaries from the firmware branch
2026-08-14 New STL
    [clamp.stl, clip.stl, cover.stl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]
2026-08-17 Fix WT32-SC01 Plus startup and display support by correcting GPIO assignments and switching to LovyanGFX
    [main.cpp]
2026-08-24 Fix WT32 wiring documentation
2026-08-26 Document background OBD-II PID polling plan
2026-08-26 Document WT32 wiring and remove unused backlight flags
2026-08-30 Add display backlight control, device health UI, and safe config migration
2026-08-30 Mark the display enclosure as designed for a 1.3-inch display
    [clip.stl, cover.stl, housing.stl]
2026-09-02 Split flash layouts by board capacity
    [partitions.csv, partitions_16mb.csv, partitions_4mb.csv]
2026-09-02 Track the source of shared vehicle metrics
2026-09-02 Discover supported OBD-II PID ranges
2026-09-02 Fix OTA slot checks for board-specific partitions
2026-09-12 Harden firmware configuration and OTA slot switching
2026-09-14 New stl fo DEVKIT1 v2
    [clip.stl, clip_big.stl, cover.stl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]
2026-10-07 Stabilize ESP32 display and stopped-engine oil status
2026-10-07 Restore the compatible DEVKIT1 flash layout and document remaining validation
    [partitions_4mb.csv]
